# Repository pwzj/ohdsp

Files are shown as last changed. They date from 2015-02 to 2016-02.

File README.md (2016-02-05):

# README #

Open Hardware DSP Platform - www.ohdsp.org

Copyright Paul Janicki 2015

Licensed under the TAPR Open Hardware License (www.tapr.org/OHL)

This documentation is distributed WITHOUT ANY EXPRESS OR IMPLIED WARRANTY, INCLUDING OF MERCHANTABILITY, SATISFACTORY QUALITY AND FITNESS FOR A PARTICULAR PURPOSE.

### What is this repository for? ###

* Quick summary

This is an (outdated) open hardware DSP platform repository. 

Please visit www.ohdsp.org and github.com/ohdsp for the latest design files and information.

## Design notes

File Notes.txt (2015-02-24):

ADAU1452:
Pn 26 SS_M/MP0 - Self boot - needs 10k pull down to GND for i2c self boot

Solders:
Bi-Sn - low temp lead free solder
http://uk.farnell.com/edsyn/cr11/solder-paste-58-42-138-deg-10g/dp/2131462

PSU:
Use LM317/337 with teddy regs!
http://www.pinkfishmedia.net/forum/showthread.php?t=39990
http://www.pinkfishmedia.net/forum/showthread.php?t=39306

Raspberry Pi Connections:
http://www.robot-electronics.co.uk/htm/raspberry_pi_examples.htm
http://pi.gadgetoid.com/pinout
http://uk.farnell.com/harwin/m20-6102045/socket-pc-104-stackthru-40way/dp/1569230
http://uk.farnell.com/te-connectivity-amp/2-534206-0/connector-receptacle-tht-40way/dp/2310167

ADI USB/I2C:
http://www.analog.com/static/imported-files/user_guides/EVAL-ADAU1452MINIZ_User_Guide.pdf

PCB Slide Switches:
http://uk.farnell.com/c-k-components/bd01/switch-1-way-spst-tht/dp/2319976

Pi I2S Info: VERY USEFUL - INFO ON CLOCKS
https://hifiduino.wordpress.com/2014/11/13/raspberry-pi-b-digital-audio/

AKM DAC Notes:
https://hifiduino.wordpress.com/2014/12/07/akm-verita-4490-dac/

PCB trace impedance:
http://chemandy.com/calculators/coplanar-waveguide-with-ground-calculator.htm

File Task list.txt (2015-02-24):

22 Jan 2015:
Add 4.7uH 4A inductor for SMPS - footprint --done 23 Jan 15

10 Feb 2015:
Add EEPROM to library - connect to master port - Done 12 Feb 15
Add Oscillator - Done 16 Feb 2015
Add thermal diode? - Note would need external temp sense IC eg ADM1032 (16 Feb 2015)
Add ADM811 to Reset - Done 12 Feb 15
Try and sequence the supplies - use two 3v3 rails, one with a soft start on enable pin, drive the 1v2 enable from 3v3 supply - done 16 Feb 15
Add raspberry pi interface to slave control port - done 16 Feb 2015
Check elektor Arduino connection and add - Just added generic I2C/SPI lines for control, also have SPI for EEPROM - 17 Feb 2015
Check eval board for ADI USB/I2C connection and add - Done 21 Feb 2015
Add raspberry pi I2S lines to one of the I2S ports - use resistors to switch to external connectors - Done 12 Feb 15

12 Feb 2015:
Add Onboard SPDIF in and DAC out? - Done 16 Feb 2015

16 Feb 2015:
Add clock fan out buffer - Done 16 Deb 2015
Do something celever with ADM811 reset power up - eg switch the power supply with pnp/npn (level translator) from DVDD so reset is low until DVDD us valid
	-- Replaced with ADM13307 and delayed supplies it correct order
Add header to allow in circuit EEPROM programming - Done 17 Feb 2015

17 Feb 2015:
Add Power Connector - screw terminals? - Done 17 Feb 2015
Delay one 3v3 supply - connect devices in right order (I2C, EEProm etc first, then DSP...) - Done 17 Feb 2015
Add protection diodes on AUXADC inputs - Done 17 Feb 2015
Add voltage clamp/polyfuse to power connectors

19 Feb 2015:
Rationalise the design!
Add a better hand solder LFCSP package - pull pad inside edges to the edge of the pad on the package

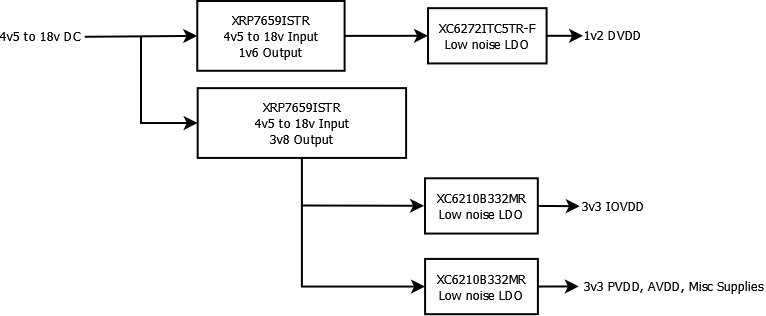
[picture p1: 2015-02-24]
Documentation/Diagrams/1. PSU/Overview V2.png

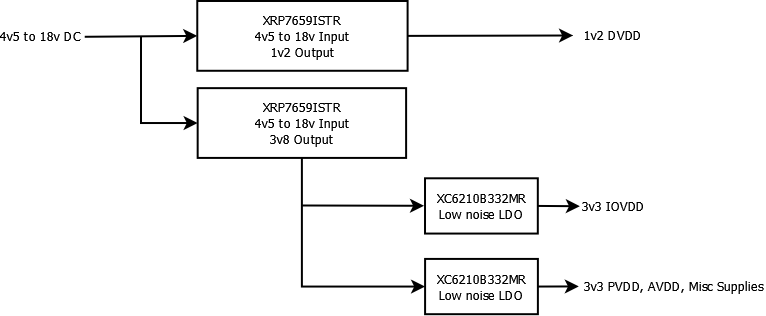
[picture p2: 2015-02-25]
Documentation/Diagrams/1. PSU/Overview V3.png

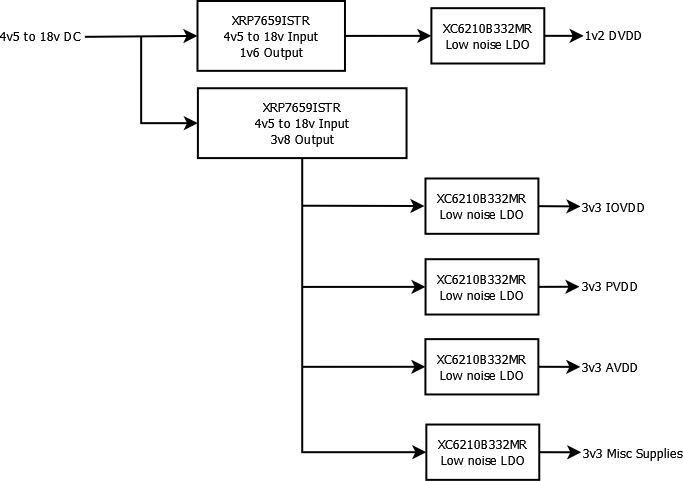
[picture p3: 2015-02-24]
Documentation/Diagrams/1. PSU/Overview.png

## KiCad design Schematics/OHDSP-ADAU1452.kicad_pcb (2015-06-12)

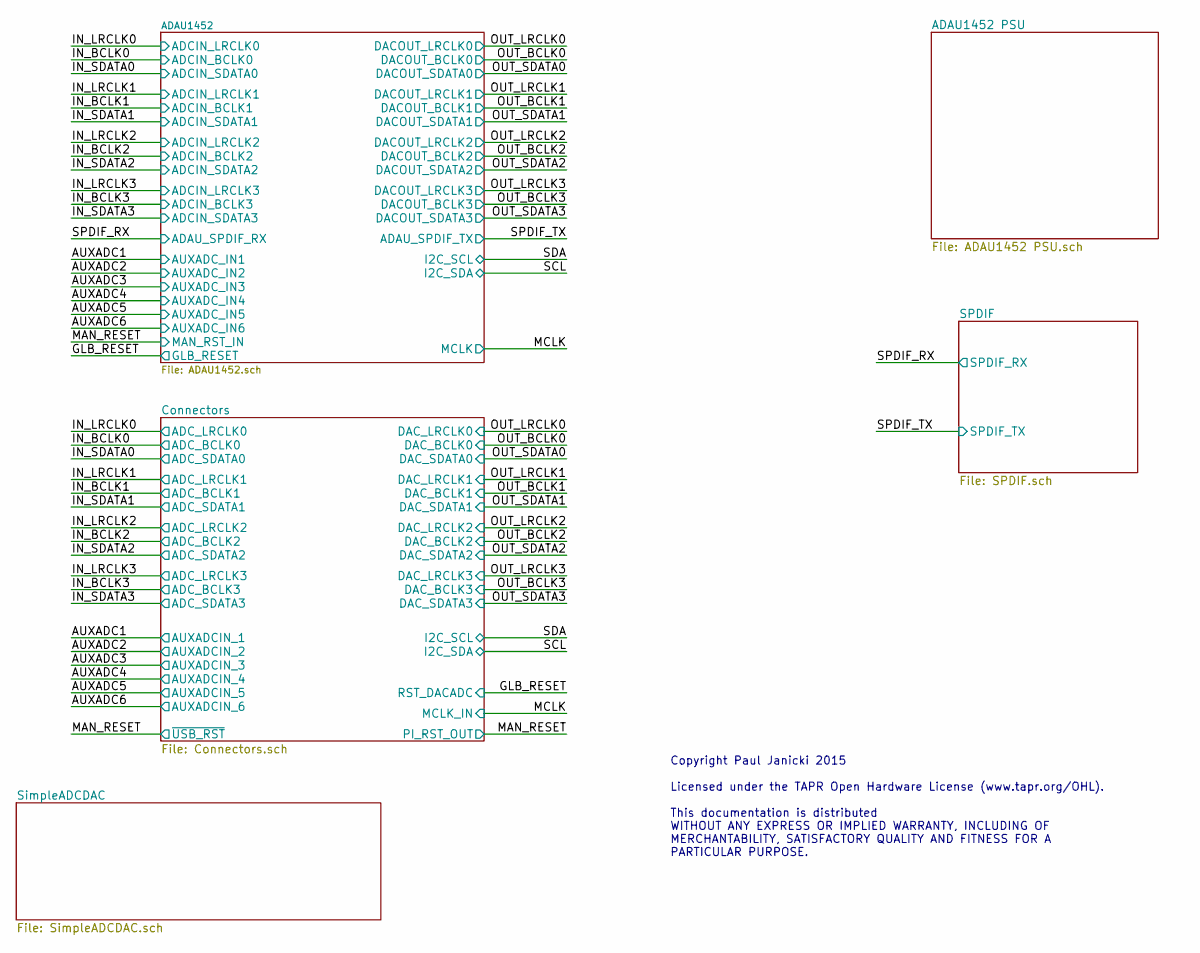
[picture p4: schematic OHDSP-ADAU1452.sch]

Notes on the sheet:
Copyright Paul Janicki 2015 Licensed under the TAPR Open Hardware License (www.tapr.org/OHL). This documentation is distributed WITHOUT ANY EXPRESS OR IMPLIED WARRANTY, INCLUDING OF MERCHANTABILITY, SATISFACTORY QUALITY AND FITNESS FOR A PARTICULAR PURPOSE.

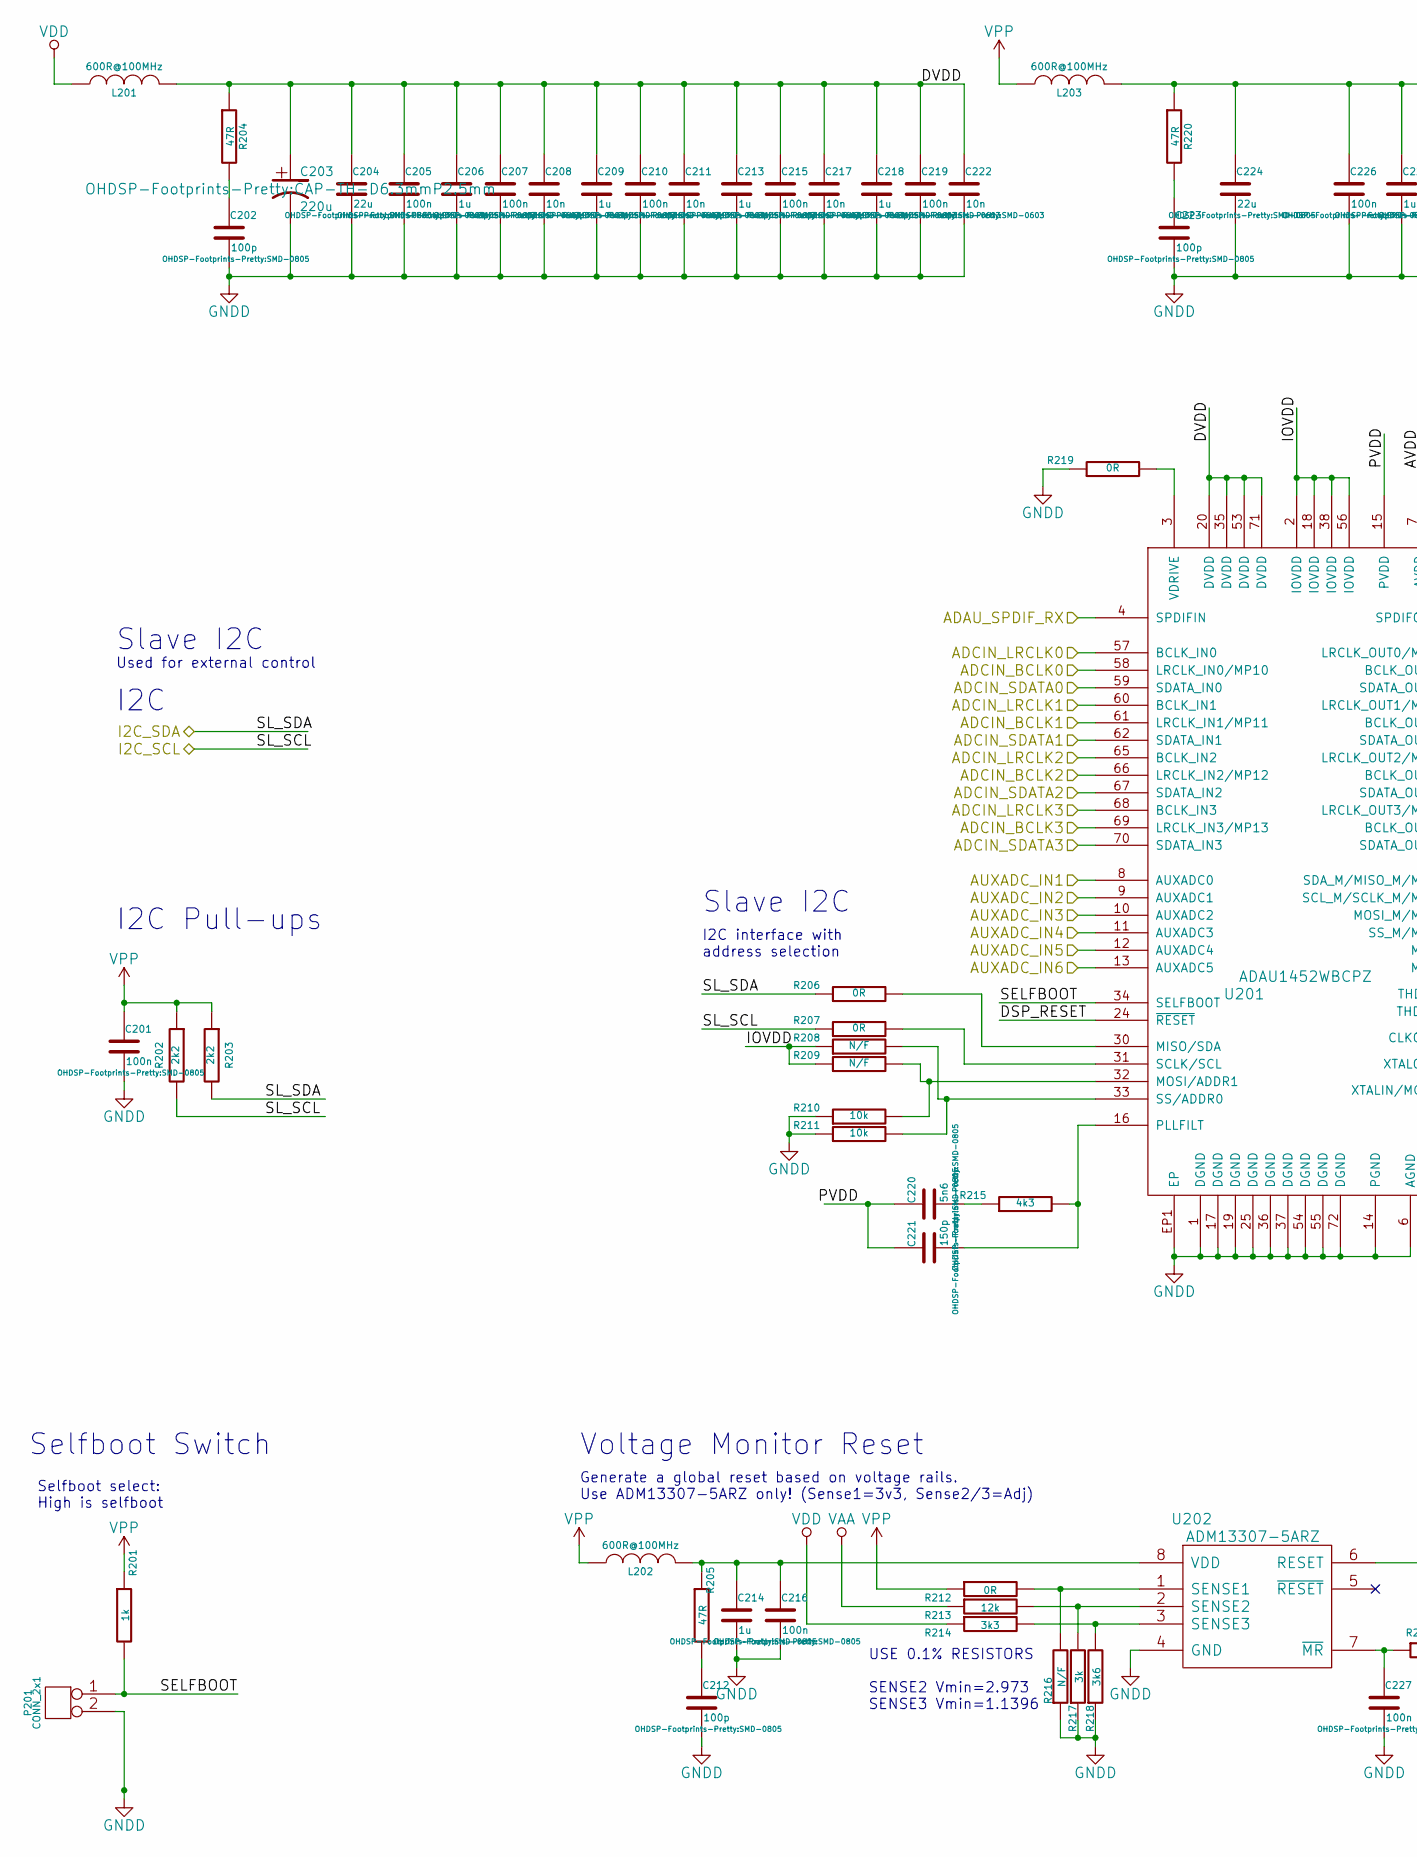
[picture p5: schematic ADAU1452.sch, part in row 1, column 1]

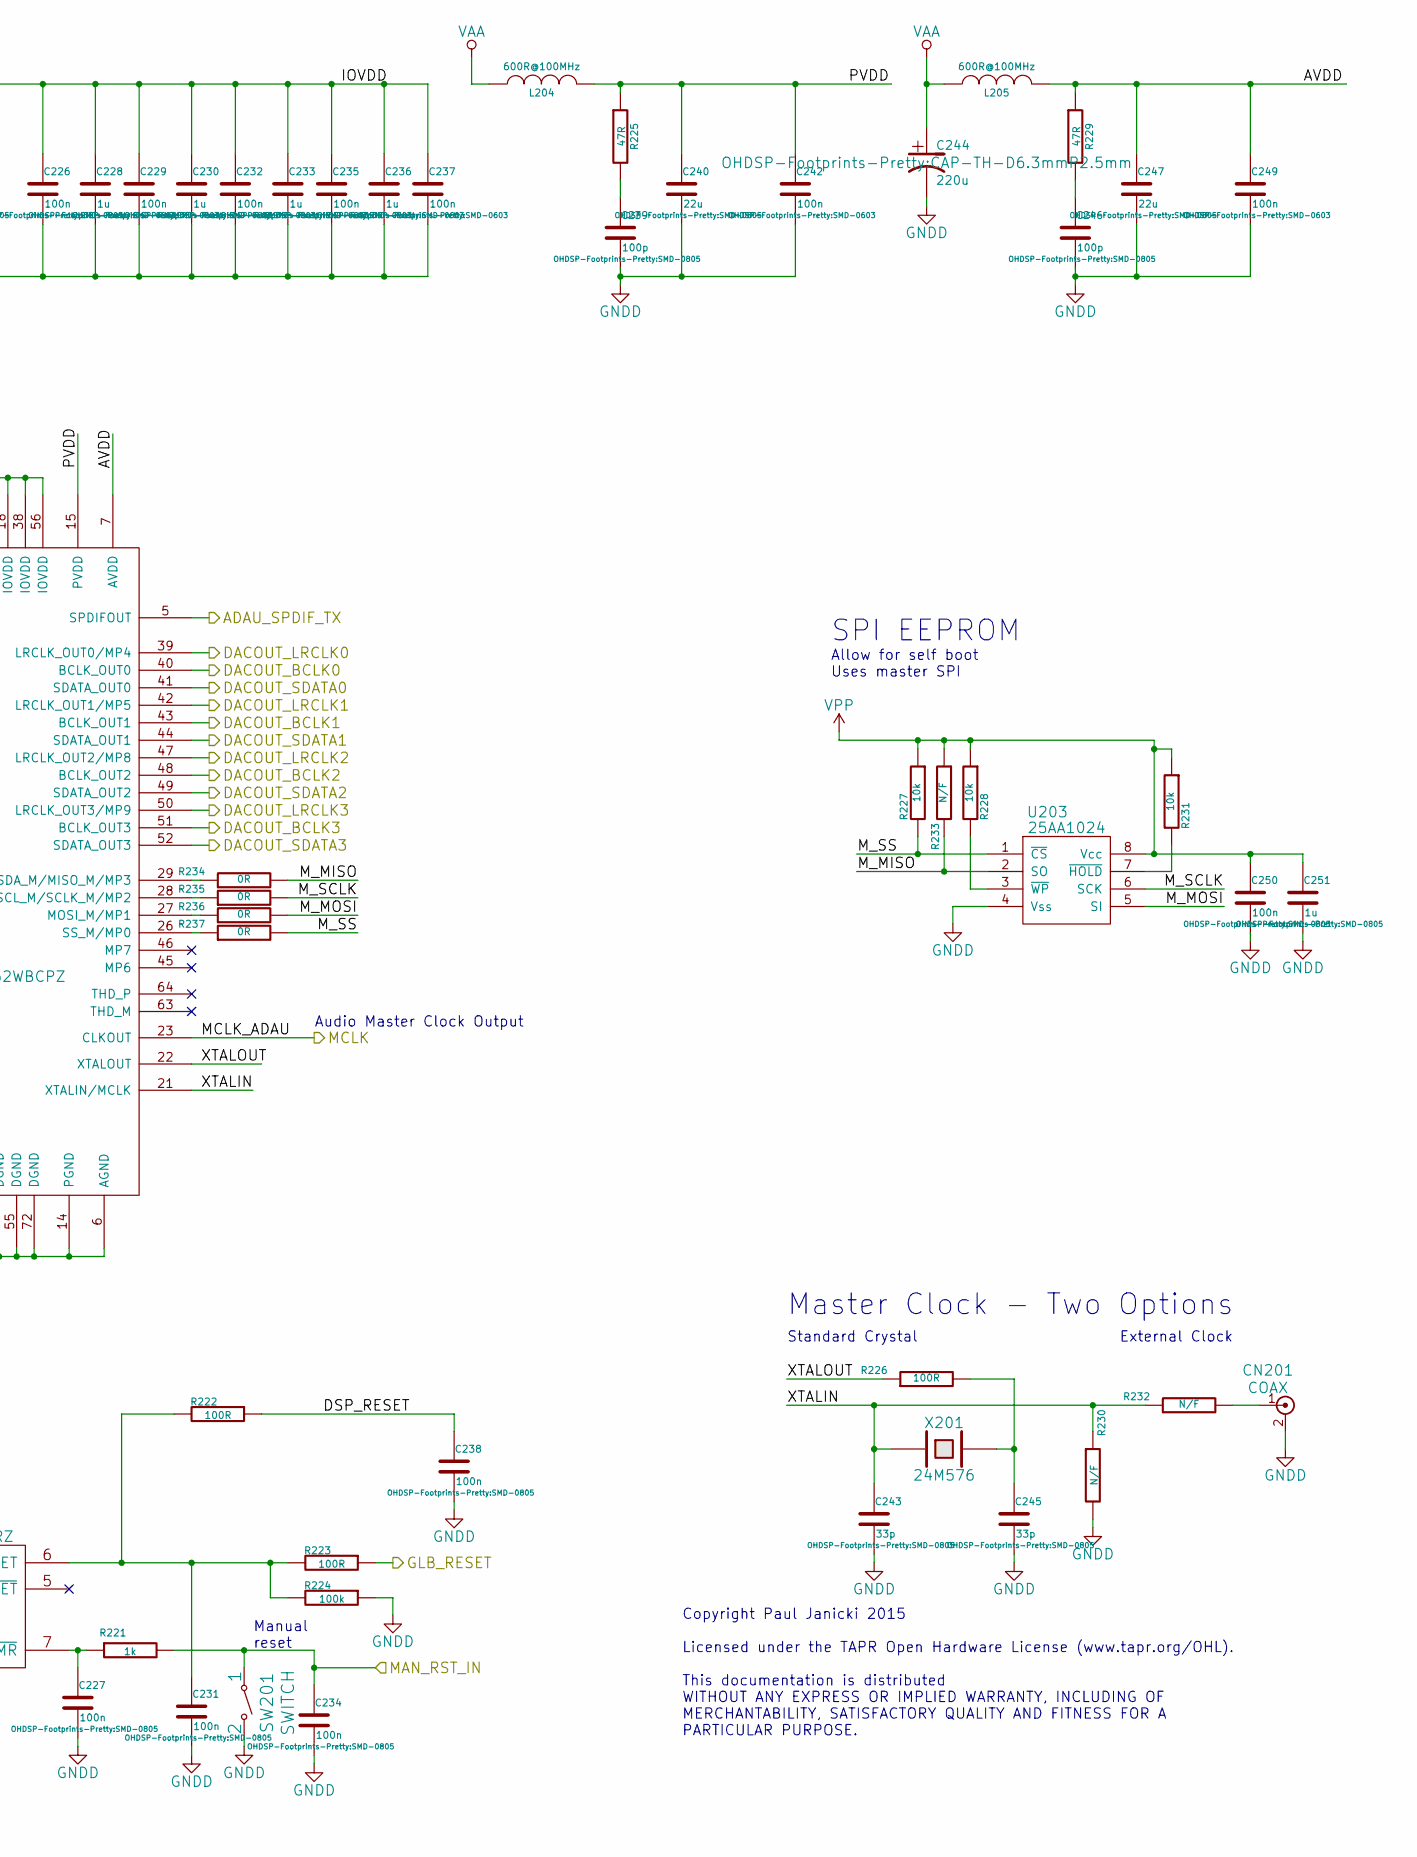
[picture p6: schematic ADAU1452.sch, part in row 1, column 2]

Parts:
C201, C205, C216, C226, C227, C231, C234, C238, C250: 100n; SMD-0805
C202, C212, C223, C239, C246: 100p; SMD-0805
C203, C244: 220u; CAP-TH-D6.3mmP2.5mm
C204, C224, C240, C247: 22u; SMD-0805
C206, C209, C213, C218, C228, C230, C233, C236: 1u; SMD-0603
C207, C210, C215, C219, C229, C232, C235, C237, C242, C249: 100n; SMD-0603
C208, C211, C217, C222: 10n; SMD-0603
C214, C251: 1u; SMD-0805
C220: 5n6; SMD-0805
C221: 150p; SMD-0805
C243, C245: 33p; SMD-0805
CN201: COAX; CONN-RF-UFL
L201, L202, L203, L204, L205: 600R@100MHz; SMD-0805
P201: CONN_2x1; CONN_SIL_2
R201, R221: 1k; SMD-0805
R202, R203: 2k2; SMD-0805
R204, R205, R220, R225, R229: 47R; SMD-0805
R206, R207, R212, R219, R234, R235, R236, R237: 0R; SMD-0805
R208, R209, R216, R230, R232, R233: N/F; SMD-0805
R210, R211, R227, R228, R231: 10k; SMD-0805
R213: 12k; SMD-0805
R214: 3k3; SMD-0805
R215: 4k3; SMD-0805
R217: 3k; SMD-0805
R218: 3k6; SMD-0805
R222, R223, R226: 100R; SMD-0805
R224: 100k; SMD-0805
SW201: SWITCH; SW_TACT_SMD
U201: ADAU1452WBCPZ; IC-LFCSP72-HANDFIT
U202: ADM13307-5ARZ; IC_SOIC_8
U203: 25AA1024; IC_DIP_8
X201: 24M576; XTAL_HC49_TH

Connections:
/ADAU1452/ADAU_SPDIF_RX: U201.4 (SPDIFIN); also elsewhere on the board
/ADAU1452/ADAU_SPDIF_TX: U201.5 (SPDIFOUT); also elsewhere on the board
/ADAU1452/ADCIN_BCLK0: U201.58 (LRCLK_IN0/MP10); also elsewhere on the board
/ADAU1452/ADCIN_BCLK1: U201.61 (LRCLK_IN1/MP11); also elsewhere on the board
/ADAU1452/ADCIN_BCLK2: U201.66 (LRCLK_IN2/MP12); also elsewhere on the board
/ADAU1452/ADCIN_BCLK3: U201.69 (LRCLK_IN3/MP13); also elsewhere on the board
/ADAU1452/ADCIN_LRCLK0: U201.57 (BCLK_IN0); also elsewhere on the board
/ADAU1452/ADCIN_LRCLK1: U201.60 (BCLK_IN1); also elsewhere on the board
/ADAU1452/ADCIN_LRCLK2: U201.65 (BCLK_IN2); also elsewhere on the board
/ADAU1452/ADCIN_LRCLK3: U201.68 (BCLK_IN3); also elsewhere on the board
/ADAU1452/ADCIN_SDATA0: U201.59 (SDATA_IN0); also elsewhere on the board
/ADAU1452/ADCIN_SDATA1: U201.62 (SDATA_IN1); also elsewhere on the board
/ADAU1452/ADCIN_SDATA2: U201.67 (SDATA_IN2); also elsewhere on the board
/ADAU1452/ADCIN_SDATA3: U201.70 (SDATA_IN3); also elsewhere on the board
/ADAU1452/AVDD: C247.1, C249.1, L205.2, R229.1, U201.7 (AVDD)
/ADAU1452/DACOUT_BCLK0: U201.40 (BCLK_OUT0); also elsewhere on the board
/ADAU1452/DACOUT_BCLK1: U201.43 (BCLK_OUT1); also elsewhere on the board
/ADAU1452/DACOUT_BCLK2: U201.48 (BCLK_OUT2); also elsewhere on the board
/ADAU1452/DACOUT_BCLK3: U201.51 (BCLK_OUT3); also elsewhere on the board
/ADAU1452/DACOUT_LRCLK0: U201.39 (LRCLK_OUT0/MP4); also elsewhere on the board
/ADAU1452/DACOUT_LRCLK1: U201.42 (LRCLK_OUT1/MP5); also elsewhere on the board
/ADAU1452/DACOUT_LRCLK2: U201.47 (LRCLK_OUT2/MP8); also elsewhere on the board
/ADAU1452/DACOUT_LRCLK3: U201.50 (LRCLK_OUT3/MP9); also elsewhere on the board
/ADAU1452/DACOUT_SDATA0: U201.41 (SDATA_OUT0); also elsewhere on the board
/ADAU1452/DACOUT_SDATA1: U201.44 (SDATA_OUT1); also elsewhere on the board
/ADAU1452/DACOUT_SDATA2: U201.49 (SDATA_OUT2); also elsewhere on the board
/ADAU1452/DACOUT_SDATA3: U201.52 (SDATA_OUT3); also elsewhere on the board
/ADAU1452/DSP_RESET: C238.1, R222.1, U201.24 (~RESET)
/ADAU1452/DVDD: C203.1, C204.1, C205.1, C206.1, C207.1, C208.1, C209.1, C210.1, C211.1, C213.1, C215.1, C217.1, C218.1, C219.1, C222.1, L201.2, R204.1, U201.20 (DVDD), U201.35 (DVDD), U201.53 (DVDD), U201.71 (DVDD)
/ADAU1452/GLB_RESET: R223.1; also elsewhere on the board
/ADAU1452/I2C_SCL: R202.2, R207.1; also elsewhere on the board
/ADAU1452/I2C_SDA: R203.2, R206.1; also elsewhere on the board
/ADAU1452/IOVDD: C224.1, C226.1, C228.1, C229.1, C230.1, C232.1, C233.1, C235.1, C236.1, C237.1, L203.2, R208.1, R209.1, R220.1, U201.2 (IOVDD), U201.18 (IOVDD), U201.38 (IOVDD), U201.56 (IOVDD)
/ADAU1452/MAN_RST_IN: C234.1, R221.2, SW201.1; also elsewhere on the board
/ADAU1452/MCLK: U201.23 (CLKOUT); also elsewhere on the board
/ADAU1452/M_MISO: R233.2, R234.2, U203.2 (SO)
/ADAU1452/M_MOSI: R236.2, U203.5 (SI)
/ADAU1452/M_SCLK: R235.2, U203.6 (SCK)
/ADAU1452/M_SS: R227.2, R237.2, U203.1 (~CS)
/ADAU1452/PVDD: C220.1, C221.1, C240.1, C242.1, L204.2, R225.1, U201.15 (PVDD)
/ADAU1452/SELFBOOT: P201.1, R201.2, U201.34 (SELFBOOT)
/ADAU1452/XTALIN: C243.1, R230.1, R232.1, U201.21 (XTALIN/MCLK), X201.1
/ADAU1452/XTALOUT: R226.1, U201.22 (XTALOUT)
/Connectors/AUXADCIN_1: U201.8 (AUXADC0); also elsewhere on the board
/Connectors/AUXADCIN_2: U201.9 (AUXADC1); also elsewhere on the board
/Connectors/AUXADCIN_3: U201.10 (AUXADC2); also elsewhere on the board
/Connectors/AUXADCIN_4: U201.11 (AUXADC3); also elsewhere on the board
/Connectors/AUXADCIN_5: U201.12 (AUXADC4); also elsewhere on the board
/Connectors/AUXADCIN_6: U201.13 (AUXADC5); also elsewhere on the board
GNDD: C201.2, C202.2, C203.2, C204.2, C205.2, C206.2, C207.2, C208.2, C209.2, C210.2, C211.2, C212.2, C213.2, C214.2, C215.2, C216.2, C217.2, C218.2, C219.2, C222.2, C223.2, C224.2, C226.2, C227.2, C228.2, C229.2, C230.2, C231.2, C232.2, C233.2, C234.2, C235.2, C236.2, C237.2, C238.2, C239.2, C240.2, C242.2, C243.2, C244.2, C245.2, C246.2, C247.2, C249.2, C250.2, C251.2, CN201.2, P201.2, R210.1, R211.1, R216.1, R217.1, R218.1, R219.1, R224.1, R230.2, SW201.2, U201.1 (DGND), U201.6 (AGND), U201.14 (PGND), U201.17 (DGND), U201.19 (DGND), U201.25 (DGND), U201.36 (DGND), U201.37 (DGND), U201.54 (DGND), U201.55 (DGND), U201.72 (DGND), U201.EP1 (EP), U202.4 (GND), U203.4 (Vss); also elsewhere on the board
unnamed: C202.1, R204.2
unnamed: C212.1, R205.2
unnamed: C214.1, C216.1, L202.2, R205.1, U202.8 (VDD)
unnamed: C220.2, R215.1
unnamed: C221.2, R215.2, U201.16 (PLLFILT)
unnamed: C223.1, R220.2
unnamed: C227.1, R221.1, U202.7 (~MR)
unnamed: C231.1, R222.2, R223.2, R224.2, U202.6 (RESET)
unnamed: C239.1, R225.2
unnamed: C245.1, R226.2, X201.2
unnamed: C246.1, R229.2
unnamed: CN201.1, R232.2
unnamed: R206.2, U201.30 (MISO/SDA)
unnamed: R207.2, U201.31 (SCLK/SCL)
unnamed: R208.2, R211.2, U201.33 (SS/ADDR0)
unnamed: R209.2, R210.2, U201.32 (MOSI/ADDR1)
unnamed: R212.2, R216.2, U202.1 (SENSE1)
unnamed: R213.2, R217.2, U202.2 (SENSE2)
unnamed: R214.2, R218.2, U202.3 (SENSE3)
unnamed: R219.2, U201.3 (VDRIVE)
unnamed: R228.2, U203.3 (~WP)
unnamed: R231.2, U203.7 (~HOLD)
unnamed: R234.1, U201.29 (SDA_M/MISO_M/MP3)
unnamed: R235.1, U201.28 (SCL_M/SCLK_M/MP2)
unnamed: R236.1, U201.27 (MOSI_M/MP1)
unnamed: R237.1, U201.26 (SS_M/MP0)
VAA: C201.1, C244.1, C250.1, C251.1, L202.1, L203.1, L204.1, L205.1, R201.1, R202.1, R203.1, R212.1, R213.1, R227.1, R228.1, R231.1, R233.1, U203.8 (Vcc); also elsewhere on the board
VDD: L201.1, R214.1; also elsewhere on the board

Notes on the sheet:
Selfboot Switch
Selfboot select: High is selfboot
Generate a global reset based on voltage rails. Use ADM13307-5ARZ only! (Sense1=3v3, Sense2/3=Adj)
Voltage Monitor Reset
SPI EEPROM
I2C Pull-ups
I2C
Master Clock - Two Options
Standard Crystal
Allow for self boot Uses master SPI
Slave I2C
Used for external control
I2C interface with address selection
Audio Master Clock Output
Manual reset
USE 0.1% RESISTORS SENSE2 Vmin=2.973 SENSE3 Vmin=1.1396
Copyright Paul Janicki 2015 Licensed under the TAPR Open Hardware License (www.tapr.org/OHL). This documentation is distributed WITHOUT ANY EXPRESS OR IMPLIED WARRANTY, INCLUDING OF MERCHANTABILITY, SATISFACTORY QUALITY AND FITNESS FOR A PARTICULAR PURPOSE.
External Clock

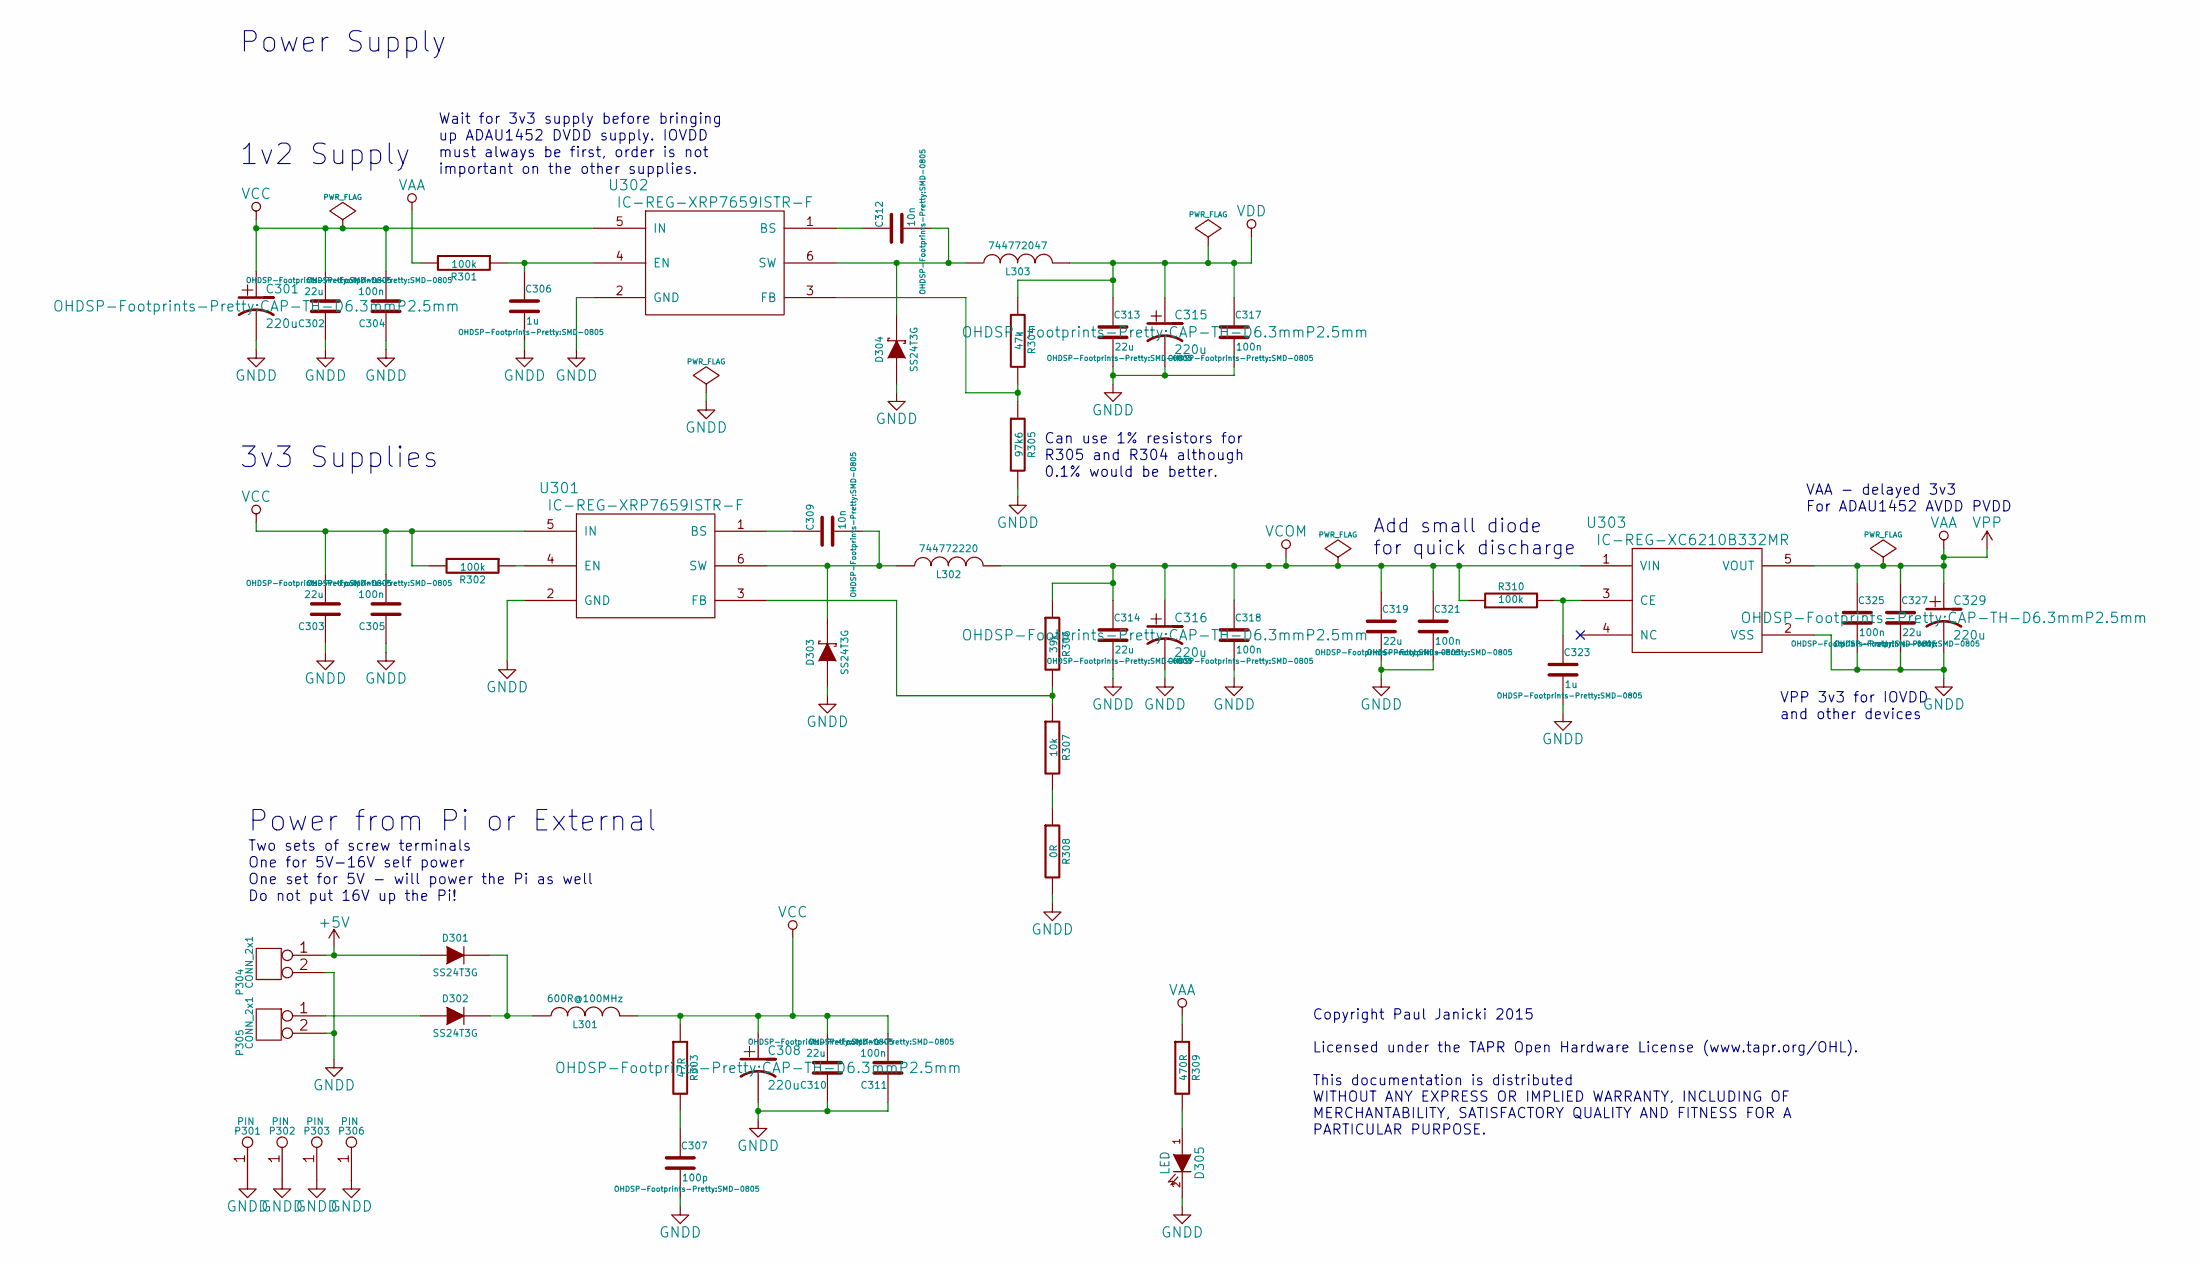
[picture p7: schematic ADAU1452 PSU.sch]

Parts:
C301, C308, C315, C316, C329: 220u; CAP-TH-D6.3mmP2.5mm
C302, C303, C310, C313, C314, C319, C327: 22u; SMD-0805
C304, C305, C311, C317, C318, C321, C325: 100n; SMD-0805
C306, C323: 1u; SMD-0805
C307: 100p; SMD-0805
C309, C312: 10n; SMD-0805
D301, D302, D303, D304: SS24T3G; DIODE-SMB
D305: LED; SMD-1206
L301: 600R@100MHz; SMD-0805
L302: 744772220; PASSIVE-TH-IND-WURTH-5mm
L303: 744772047; PASSIVE-TH-IND-WURTH-5mm
P301, P302, P303, P306: PIN; MNT_HOLE_2.5mm
P304, P305: CONN_2x1; CONN-SCREW-2WAY-5mm-5.08mm
R301, R302, R310: 100k; SMD-0805
R303: 47R; SMD-0805
R304: 47k; SMD-0805
R305: 97k6; SMD-0805
R306: 39k; SMD-0805
R307: 10k; SMD-0805
R308: 0R; SMD-0805
R309: 470R; SMD-0805
U301, U302: IC-REG-XRP7659ISTR-F; IC-SOT23-6
U303: IC-REG-XC6210B332MR; IC-SOT25

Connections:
+5V: D301.1 (A), P304.1; also elsewhere on the board
GNDD: C301.2, C302.1, C303.1, C304.1, C305.1, C306.2, C307.2, C308.2, C310.1, C311.1, C313.2, C314.2, C315.2, C316.2, C317.2, C318.2, C319.2, C321.2, C323.2, C325.2, C327.2, C329.2, D303.1 (A), D304.1 (A), D305.2 (K), P301.1, P302.1, P303.1, P304.2, P305.2, P306.1, R305.2, R308.2, U301.2 (GND), U302.2 (GND), U303.2 (VSS); also elsewhere on the board
unnamed: C306.1, R301.1, U302.4 (EN)
unnamed: C307.1, R303.2
unnamed: C309.1, U301.1 (BS)
unnamed: C309.2, D303.2 (K), L302.1, U301.6 (SW)
unnamed: C312.1, U302.1 (BS)
unnamed: C312.2, D304.2 (K), L303.1, U302.6 (SW)
unnamed: C323.1, R310.2, U303.3 (CE)
unnamed: D301.2 (K), D302.2 (K), L301.1
unnamed: D302.1 (A), P305.1
unnamed: D305.1 (A), R309.2
unnamed: R302.1, U301.4 (EN)
unnamed: R304.2, R305.1, U302.3 (FB)
unnamed: R306.2, R307.1, U301.3 (FB)
unnamed: R307.2, R308.1
VAA: C325.1, C327.1, C329.1, R301.2, R309.1, U303.5 (VOUT); also elsewhere on the board
VCC: C301.1, C302.2, C303.2, C304.2, C305.2, C308.1, C310.2, C311.2, L301.2, R302.2, R303.1, U301.5 (IN), U302.5 (IN)
VCOM: C314.1, C316.1, C318.1, C319.1, C321.1, L302.2, R306.1, R310.1, U303.1 (VIN)
VDD: C313.1, C315.1, C317.1, L303.2, R304.1; also elsewhere on the board

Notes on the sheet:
Wait for 3v3 supply before bringing up ADAU1452 DVDD supply. IOVDD must always be first, order is not important on the other supplies.
Power Supply
1v2 Supply
3v3 Supplies
VAA - delayed 3v3 For ADAU1452 AVDD PVDD
VPP 3v3 for IOVDD and other devices
Power from Pi or External
Two sets of screw terminals One for 5V-16V self power One set for 5V - will power the Pi as well Do not put 16V up the Pi!
Copyright Paul Janicki 2015 Licensed under the TAPR Open Hardware License (www.tapr.org/OHL). This documentation is distributed WITHOUT ANY EXPRESS OR IMPLIED WARRANTY, INCLUDING OF MERCHANTABILITY, SATISFACTORY QUALITY AND FITNESS FOR A PARTICULAR PURPOSE.
Add small diode for quick discharge
Can use 1% resistors for R305 and R304 although 0.1% would be better.

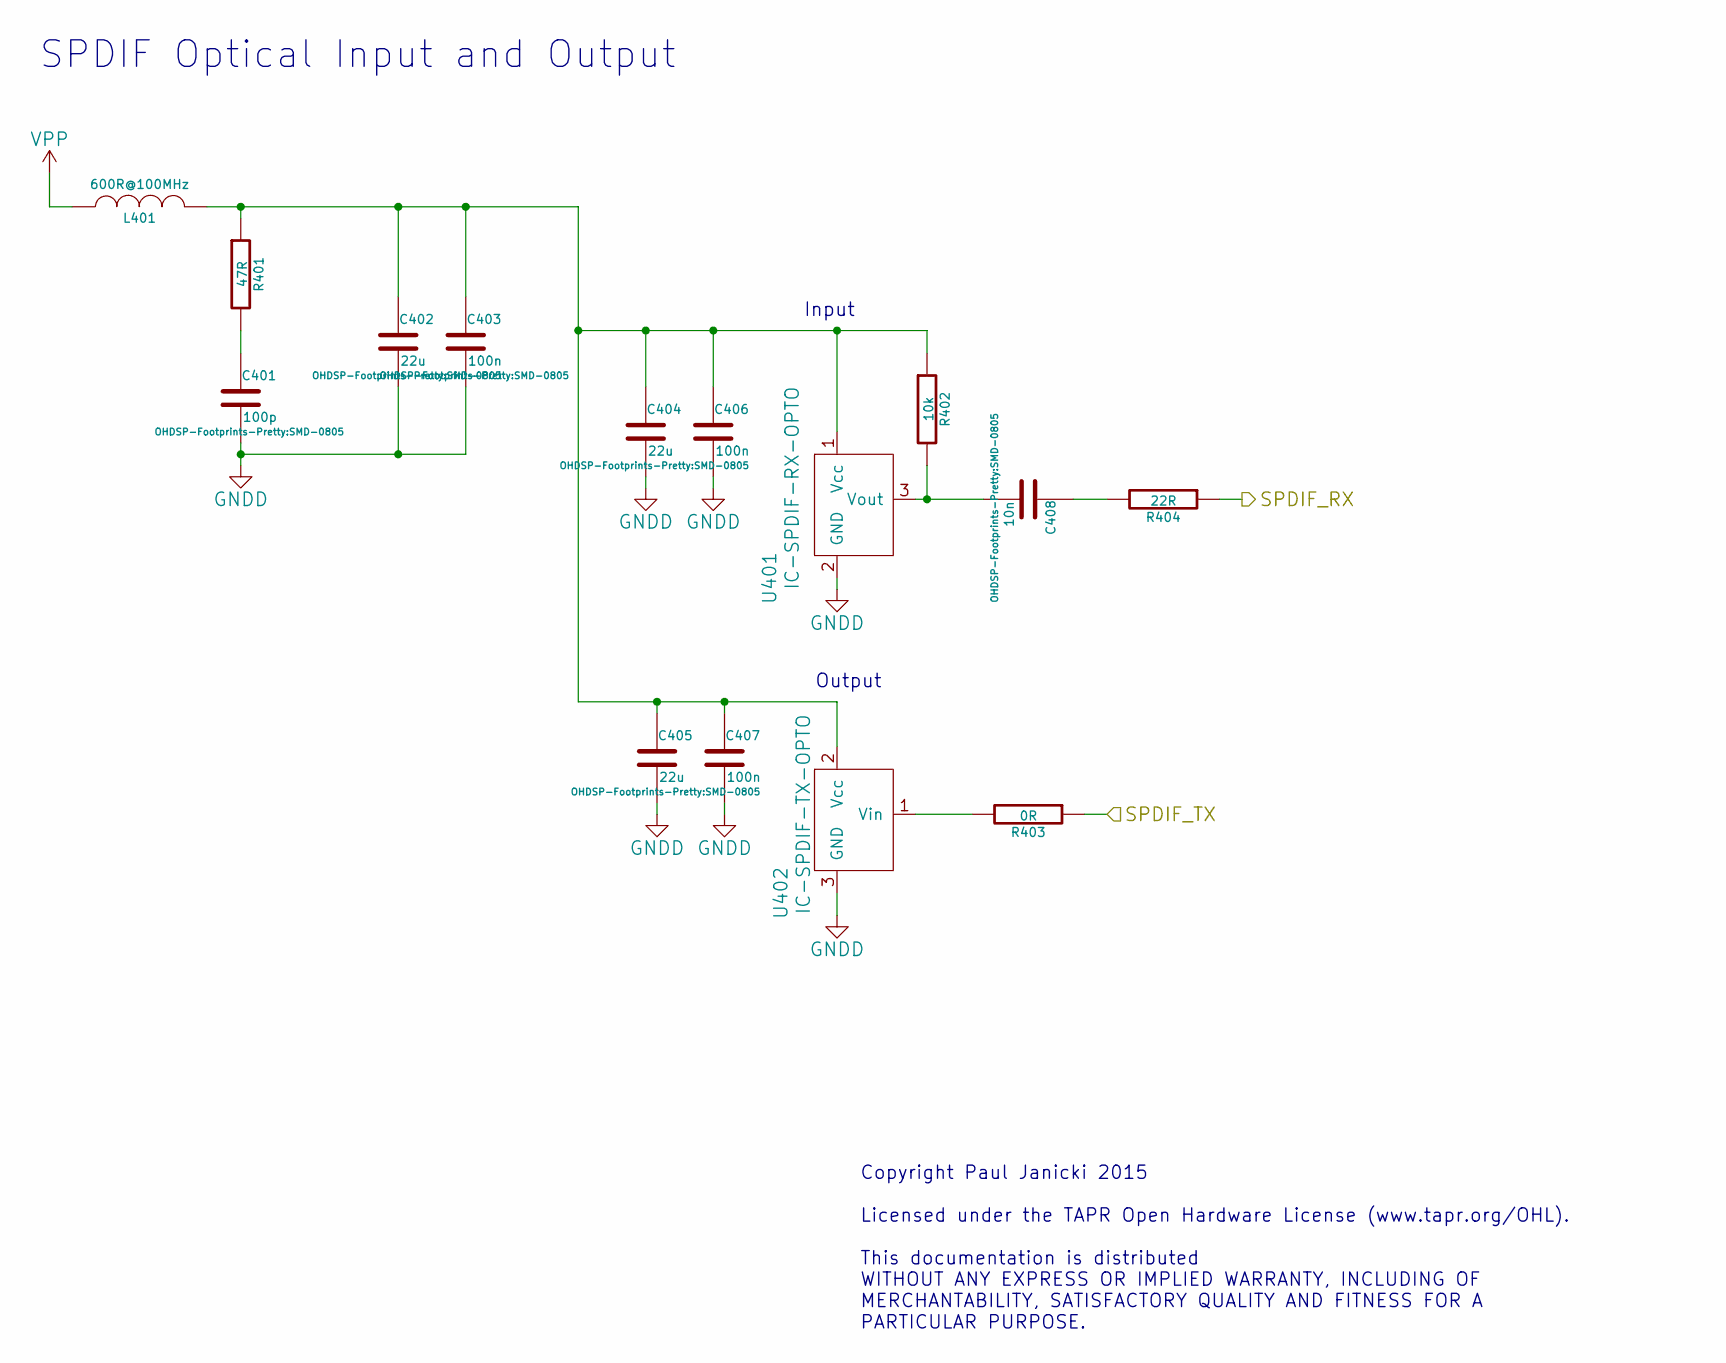
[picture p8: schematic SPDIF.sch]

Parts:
C401: 100p; SMD-0805
C402, C404, C405: 22u; SMD-0805
C403, C406, C407: 100n; SMD-0805
C408: 10n; SMD-0805
L401: 600R@100MHz; SMD-0805
R401: 47R; SMD-0805
R402: 10k; SMD-0805
R403: 0R; SMD-0805
R404: 22R; SMD-0805
U401: IC-SPDIF-RX-OPTO; IC_SPDIF_OPTO
U402: IC-SPDIF-TX-OPTO; IC_SPDIF_OPTO

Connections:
/ADAU1452/ADAU_SPDIF_RX: R404.1; also elsewhere on the board
/ADAU1452/ADAU_SPDIF_TX: R403.1; also elsewhere on the board
GNDD: C401.2, C402.2, C403.2, C404.2, C405.2, C406.2, C407.2, U401.2 (GND), U402.3 (GND); also elsewhere on the board
unnamed: C401.1, R401.2
unnamed: C402.1, C403.1, C404.1, C405.1, C406.1, C407.1, L401.2, R401.1, R402.1, U401.1 (Vcc), U402.2 (Vcc)
unnamed: C408.1, R404.2
unnamed: C408.2, R402.2, U401.3 (Vout)
unnamed: R403.2, U402.1 (Vin)
VAA: L401.1; also elsewhere on the board

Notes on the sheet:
SPDIF Optical Input and Output
Input
Output
Copyright Paul Janicki 2015 Licensed under the TAPR Open Hardware License (www.tapr.org/OHL). This documentation is distributed WITHOUT ANY EXPRESS OR IMPLIED WARRANTY, INCLUDING OF MERCHANTABILITY, SATISFACTORY QUALITY AND FITNESS FOR A PARTICULAR PURPOSE.

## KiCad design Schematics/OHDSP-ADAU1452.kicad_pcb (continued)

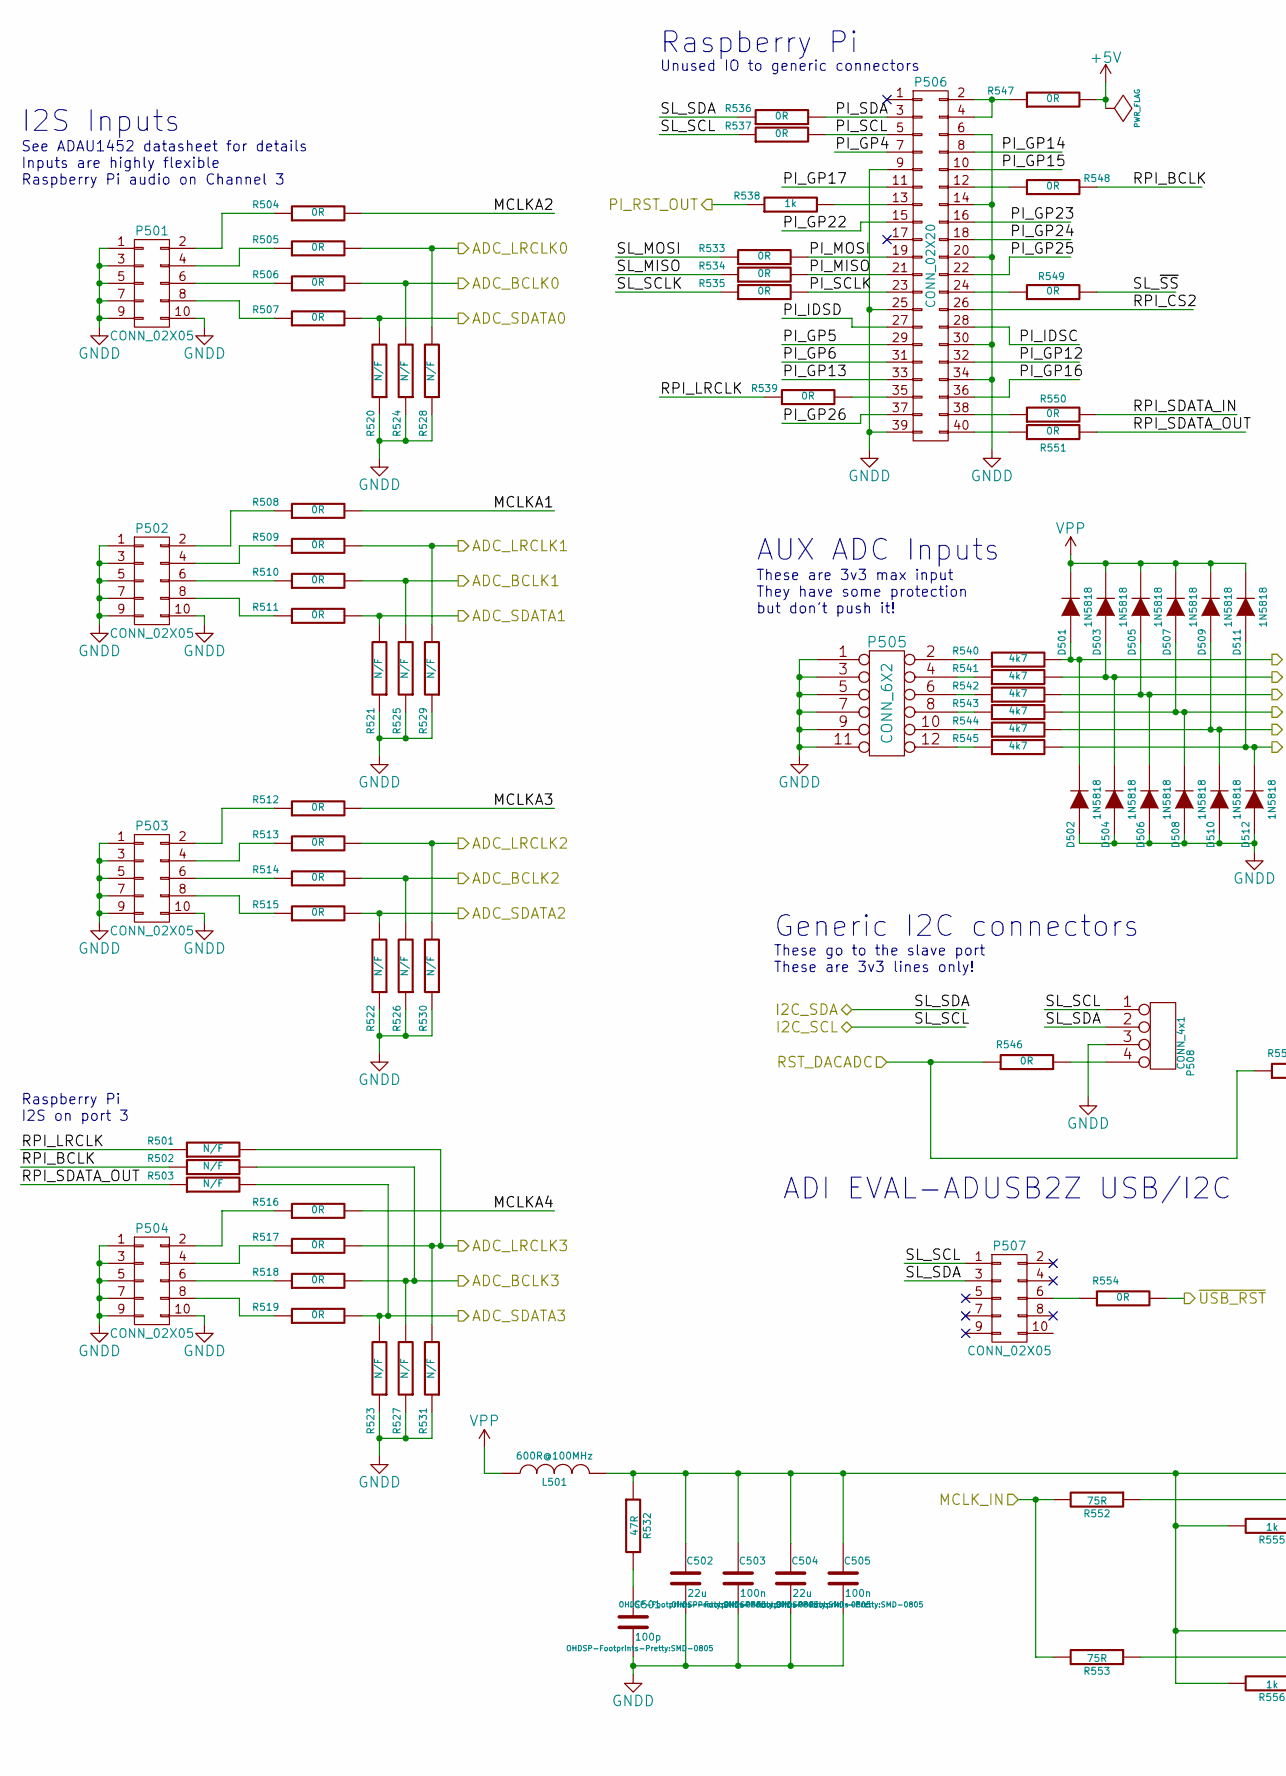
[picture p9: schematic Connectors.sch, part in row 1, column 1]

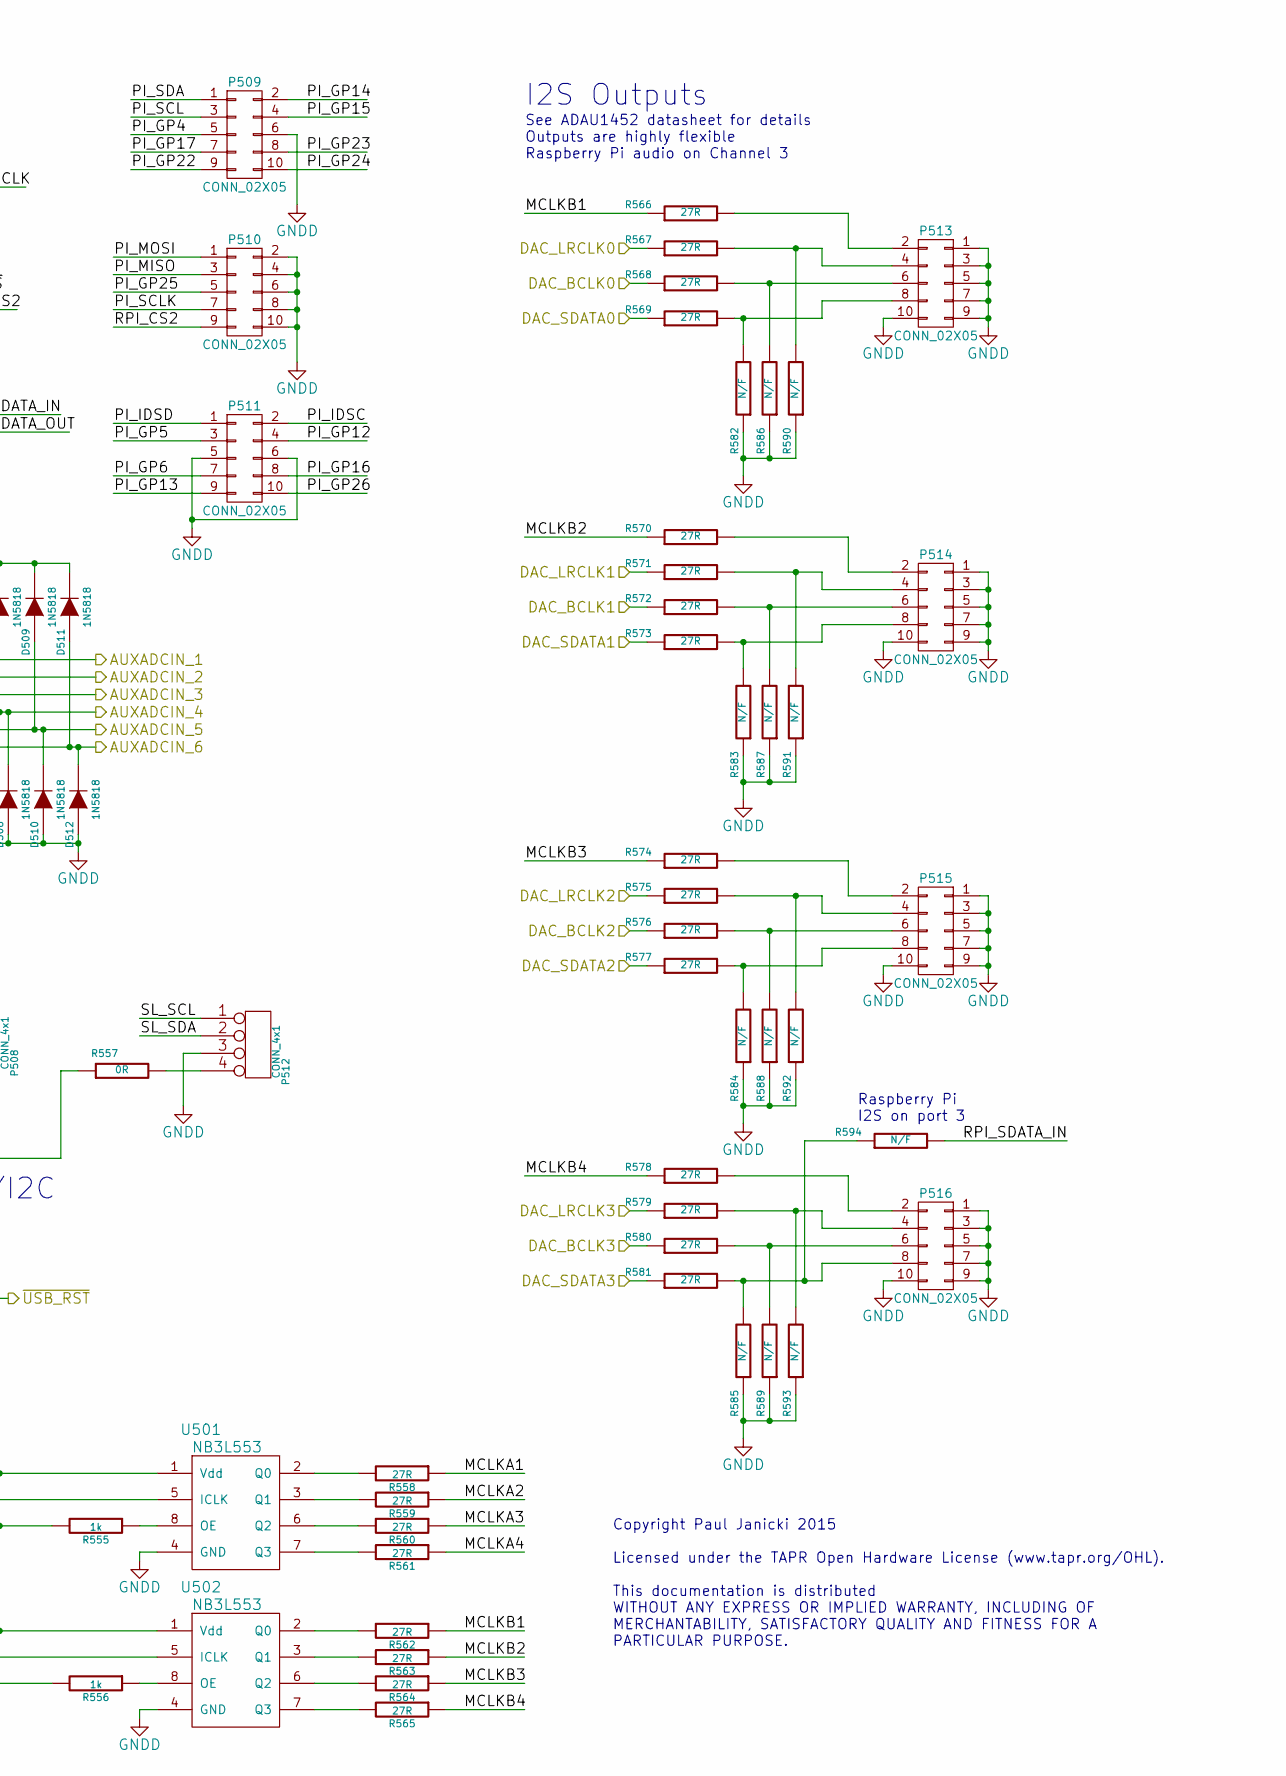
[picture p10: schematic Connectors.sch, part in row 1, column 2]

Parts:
C501: 100p; SMD-0805
C502, C504: 22u; SMD-0805
C503, C505: 100n; SMD-0805
D501, D502, D503, D504, D505, D506, D507, D508, D509, D510, D511, D512: 1N5818; DIODE-DO-41
L501: 600R@100MHz; SMD-0805
P501, P502, P503, P504, P507, P513, P514, P515, P516: CONN_02X05; CONN_DIL_2X5_BOX
P505: CONN_6X2; CONN_DIL_2X6
P506: CONN_02X20; CONN_DIL_2X20
P508, P512: CONN_4x1; CONN_SIL_4
P509, P510, P511: CONN_02X05; CONN_DIL_2X5
R501, R502, R503, R520, R521, R522, R523, R524, R525, R526, R527, R528, R529, R530, R531, R582, R583, R584, R585, R586, R587, R588, R589, R590, R591, R592, R593, R594: N/F; SMD-0805
R504, R505, R506, R507, R508, R509, R510, R511, R512, R513, R514, R515, R516, R517, R518, R519, R533, R534, R535, R536, R537, R539, R546, R547, R548, R549, R550, R551, R554, R557: 0R; SMD-0805
R532: 47R; SMD-0805
R538, R555, R556: 1k; SMD-0805
R540, R541, R542, R543, R544, R545: 4k7; SMD-0805
R552, R553: 75R; SMD-0805
R558, R559, R560, R561, R562, R563, R564, R565, R566, R567, R568, R569, R570, R571, R572, R573, R574, R575, R576, R577, R578, R579, R580, R581: 27R; SMD-0805
U501, U502: NB3L553; IC_SOIC_8

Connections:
+5V: R547.2; also elsewhere on the board
/ADAU1452/ADCIN_BCLK0: R506.2, R524.2; also elsewhere on the board
/ADAU1452/ADCIN_BCLK1: R510.2, R525.2; also elsewhere on the board
/ADAU1452/ADCIN_BCLK2: R514.2, R526.2; also elsewhere on the board
/ADAU1452/ADCIN_BCLK3: R502.2, R518.2, R527.2; also elsewhere on the board
/ADAU1452/ADCIN_LRCLK0: R505.2, R528.2; also elsewhere on the board
/ADAU1452/ADCIN_LRCLK1: R509.2, R529.2; also elsewhere on the board
/ADAU1452/ADCIN_LRCLK2: R513.2, R530.2; also elsewhere on the board
/ADAU1452/ADCIN_LRCLK3: R501.2, R517.2, R531.2; also elsewhere on the board
/ADAU1452/ADCIN_SDATA0: R507.2, R520.2; also elsewhere on the board
/ADAU1452/ADCIN_SDATA1: R511.2, R521.2; also elsewhere on the board
/ADAU1452/ADCIN_SDATA2: R515.2, R522.2; also elsewhere on the board
/ADAU1452/ADCIN_SDATA3: R503.2, R519.2, R523.2; also elsewhere on the board
/ADAU1452/DACOUT_BCLK0: R568.1; also elsewhere on the board
/ADAU1452/DACOUT_BCLK1: R572.1; also elsewhere on the board
/ADAU1452/DACOUT_BCLK2: R576.1; also elsewhere on the board
/ADAU1452/DACOUT_BCLK3: R580.1; also elsewhere on the board
/ADAU1452/DACOUT_LRCLK0: R567.1; also elsewhere on the board
/ADAU1452/DACOUT_LRCLK1: R571.1; also elsewhere on the board
/ADAU1452/DACOUT_LRCLK2: R575.1; also elsewhere on the board
/ADAU1452/DACOUT_LRCLK3: R579.1; also elsewhere on the board
/ADAU1452/DACOUT_SDATA0: R569.1; also elsewhere on the board
/ADAU1452/DACOUT_SDATA1: R573.1; also elsewhere on the board
/ADAU1452/DACOUT_SDATA2: R577.1; also elsewhere on the board
/ADAU1452/DACOUT_SDATA3: R581.1; also elsewhere on the board
/ADAU1452/GLB_RESET: R546.1, R557.1; also elsewhere on the board
/ADAU1452/I2C_SCL: P507.1, P508.1, P512.1, R537.1; also elsewhere on the board
/ADAU1452/I2C_SDA: P507.3, P508.2, P512.2, R536.1; also elsewhere on the board
/ADAU1452/MAN_RST_IN: R538.1, R554.2; also elsewhere on the board
/ADAU1452/MCLK: R552.2, R553.2; also elsewhere on the board
/Connectors/AUXADCIN_1: D501.1 (A), D502.2 (K), R540.2; also elsewhere on the board
/Connectors/AUXADCIN_2: D503.1 (A), D504.2 (K), R541.2; also elsewhere on the board
/Connectors/AUXADCIN_3: D505.1 (A), D506.2 (K), R542.2; also elsewhere on the board
/Connectors/AUXADCIN_4: D507.1 (A), D508.2 (K), R543.2; also elsewhere on the board
/Connectors/AUXADCIN_5: D509.1 (A), D510.2 (K), R544.2; also elsewhere on the board
/Connectors/AUXADCIN_6: D511.1 (A), D512.2 (K), R545.2; also elsewhere on the board
/Connectors/MCLKA1: R508.2, R558.1
/Connectors/MCLKA2: R504.2, R559.1
/Connectors/MCLKA3: R512.2, R560.1
/Connectors/MCLKA4: R516.2, R561.1
/Connectors/MCLKB1: R562.1, R566.1
/Connectors/MCLKB2: R563.1, R570.1
/Connectors/MCLKB3: R564.1, R574.1
/Connectors/MCLKB4: R565.1, R578.1
/Connectors/PI_GP4: P506.7, P509.5
/Connectors/PI_GP5: P506.29, P511.3
/Connectors/PI_GP6: P506.31, P511.7
/Connectors/PI_GP12: P506.32, P511.4
/Connectors/PI_GP13: P506.33, P511.9
/Connectors/PI_GP14: P506.8, P509.2
/Connectors/PI_GP15: P506.10, P509.4
/Connectors/PI_GP16: P506.36, P511.8
/Connectors/PI_GP17: P506.11, P509.7
/Connectors/PI_GP22: P506.15, P509.9
/Connectors/PI_GP23: P506.16, P509.8
/Connectors/PI_GP24: P506.18, P509.10
/Connectors/PI_GP25: P506.22, P510.5
/Connectors/PI_GP26: P506.37, P511.10
/Connectors/PI_IDSC: P506.28, P511.2
/Connectors/PI_IDSD: P506.27, P511.1
/Connectors/PI_MISO: P506.21, P510.3, R534.2
/Connectors/PI_MOSI: P506.19, P510.1, R533.2
/Connectors/PI_SCL: P506.5, P509.3, R537.2
/Connectors/PI_SCLK: P506.23, P510.7, R535.2
/Connectors/PI_SDA: P506.3, P509.1, R536.2
/Connectors/RPI_BCLK: R502.1, R548.2
/Connectors/RPI_CS2: P506.26, P510.9
/Connectors/RPI_LRCLK: R501.1, R539.1
/Connectors/RPI_SDATA_IN: R550.2, R594.2
/Connectors/RPI_SDATA_OUT: R503.1, R551.2
/Connectors/SL_MISO: R534.1
/Connectors/SL_MOSI: R533.1
/Connectors/SL_SCLK: R535.1
/Connectors/SL_~SS: R549.2
GNDD: C501.2, C502.2, C503.2, C504.2, C505.2, D502.1 (A), D504.1 (A), D506.1 (A), D508.1 (A), D510.1 (A), D512.1 (A), P501.1, P501.3, P501.5, P501.7, P501.9, P501.10, P502.1, P502.3, P502.5, P502.7, P502.9, P502.10, P503.1, P503.3, P503.5, P503.7, P503.9, P503.10, P504.1, P504.3, P504.5, P504.7, P504.9, P504.10, P505.1, P505.3, P505.5, P505.7, P505.9, P505.11, P506.6, P506.9, P506.14, P506.20, P506.25, P506.30, P506.34, P506.39, P508.3, P509.6, P510.2, P510.4, P510.6, P510.8, P510.10, P511.5, P511.6, P512.3, P513.1, P513.3, P513.5, P513.7, P513.9, P513.10, P514.1, P514.3, P514.5, P514.7, P514.9, P514.10, P515.1, P515.3, P515.5, P515.7, P515.9, P515.10, P516.1, P516.3, P516.5, P516.7, P516.9, P516.10, R520.1, R521.1, R522.1, R523.1, R524.1, R525.1, R526.1, R527.1, R528.1, R529.1, R530.1, R531.1, R582.1, R583.1, R584.1, R585.1, R586.1, R587.1, R588.1, R589.1, R590.1, R591.1, R592.1, R593.1, U501.4 (GND), U502.4 (GND); also elsewhere on the board
unnamed: C501.1, R532.2
unnamed: C502.1, C503.1, C504.1, C505.1, L501.2, R532.1, R555.2, R556.2, U501.1 (Vdd), U502.1 (Vdd)
unnamed: P501.2, R504.1
unnamed: P501.4, R505.1
unnamed: P501.6, R506.1
unnamed: P501.8, R507.1
unnamed: P502.2, R508.1
unnamed: P502.4, R509.1
unnamed: P502.6, R510.1
unnamed: P502.8, R511.1
unnamed: P503.2, R512.1
unnamed: P503.4, R513.1
unnamed: P503.6, R514.1
unnamed: P503.8, R515.1
unnamed: P504.2, R516.1
unnamed: P504.4, R517.1
unnamed: P504.6, R518.1
unnamed: P504.8, R519.1
unnamed: P505.2, R540.1
unnamed: P505.4, R541.1
unnamed: P505.6, R542.1
unnamed: P505.8, R543.1
unnamed: P505.10, R544.1
unnamed: P505.12, R545.1
unnamed: P506.2, P506.4, R547.1
unnamed: P506.12, R548.1
unnamed: P506.13, R538.2
unnamed: P506.24, R549.1
unnamed: P506.35, R539.2
unnamed: P506.38, R550.1
unnamed: P506.40, R551.1
unnamed: P507.6, R554.1
unnamed: P508.4, R546.2
unnamed: P512.4, R557.2
unnamed: P513.2, R566.2
unnamed: P513.4, R567.2, R590.2
unnamed: P513.6, R568.2, R586.2
unnamed: P513.8, R569.2, R582.2
unnamed: P514.2, R570.2
unnamed: P514.4, R571.2, R591.2
unnamed: P514.6, R572.2, R587.2
unnamed: P514.8, R573.2, R583.2
unnamed: P515.2, R574.2
unnamed: P515.4, R575.2, R592.2
unnamed: P515.6, R576.2, R588.2
unnamed: P515.8, R577.2, R584.2
unnamed: P516.2, R578.2
unnamed: P516.4, R579.2, R593.2
unnamed: P516.6, R580.2, R589.2
unnamed: P516.8, R581.2, R585.2, R594.1
unnamed: R552.1, U501.5 (ICLK)
unnamed: R553.1, U502.5 (ICLK)
unnamed: R555.1, U501.8 (OE)
unnamed: R556.1, U502.8 (OE)
unnamed: R558.2, U501.2 (Q0)
unnamed: R559.2, U501.3 (Q1)
unnamed: R560.2, U501.6 (Q2)
unnamed: R561.2, U501.7 (Q3)
unnamed: R562.2, U502.2 (Q0)
unnamed: R563.2, U502.3 (Q1)
unnamed: R564.2, U502.6 (Q2)
unnamed: R565.2, U502.7 (Q3)
VAA: D501.2 (K), D503.2 (K), D505.2 (K), D507.2 (K), D509.2 (K), D511.2 (K), L501.1; also elsewhere on the board

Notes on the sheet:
ADI EVAL-ADUSB2Z USB/I2C
Raspberry Pi
Raspberry Pi I2S on port 3
AUX ADC Inputs
Generic I2C connectors
These go to the slave port These are 3v3 lines only!
I2S Inputs
See ADAU1452 datasheet for details Inputs are highly flexible Raspberry Pi audio on Channel 3
I2S Outputs
See ADAU1452 datasheet for details Outputs are highly flexible Raspberry Pi audio on Channel 3
These are 3v3 max input They have some protection but don't push it!
Copyright Paul Janicki 2015 Licensed under the TAPR Open Hardware License (www.tapr.org/OHL). This documentation is distributed WITHOUT ANY EXPRESS OR IMPLIED WARRANTY, INCLUDING OF MERCHANTABILITY, SATISFACTORY QUALITY AND FITNESS FOR A PARTICULAR PURPOSE.
Unused IO to generic connectors

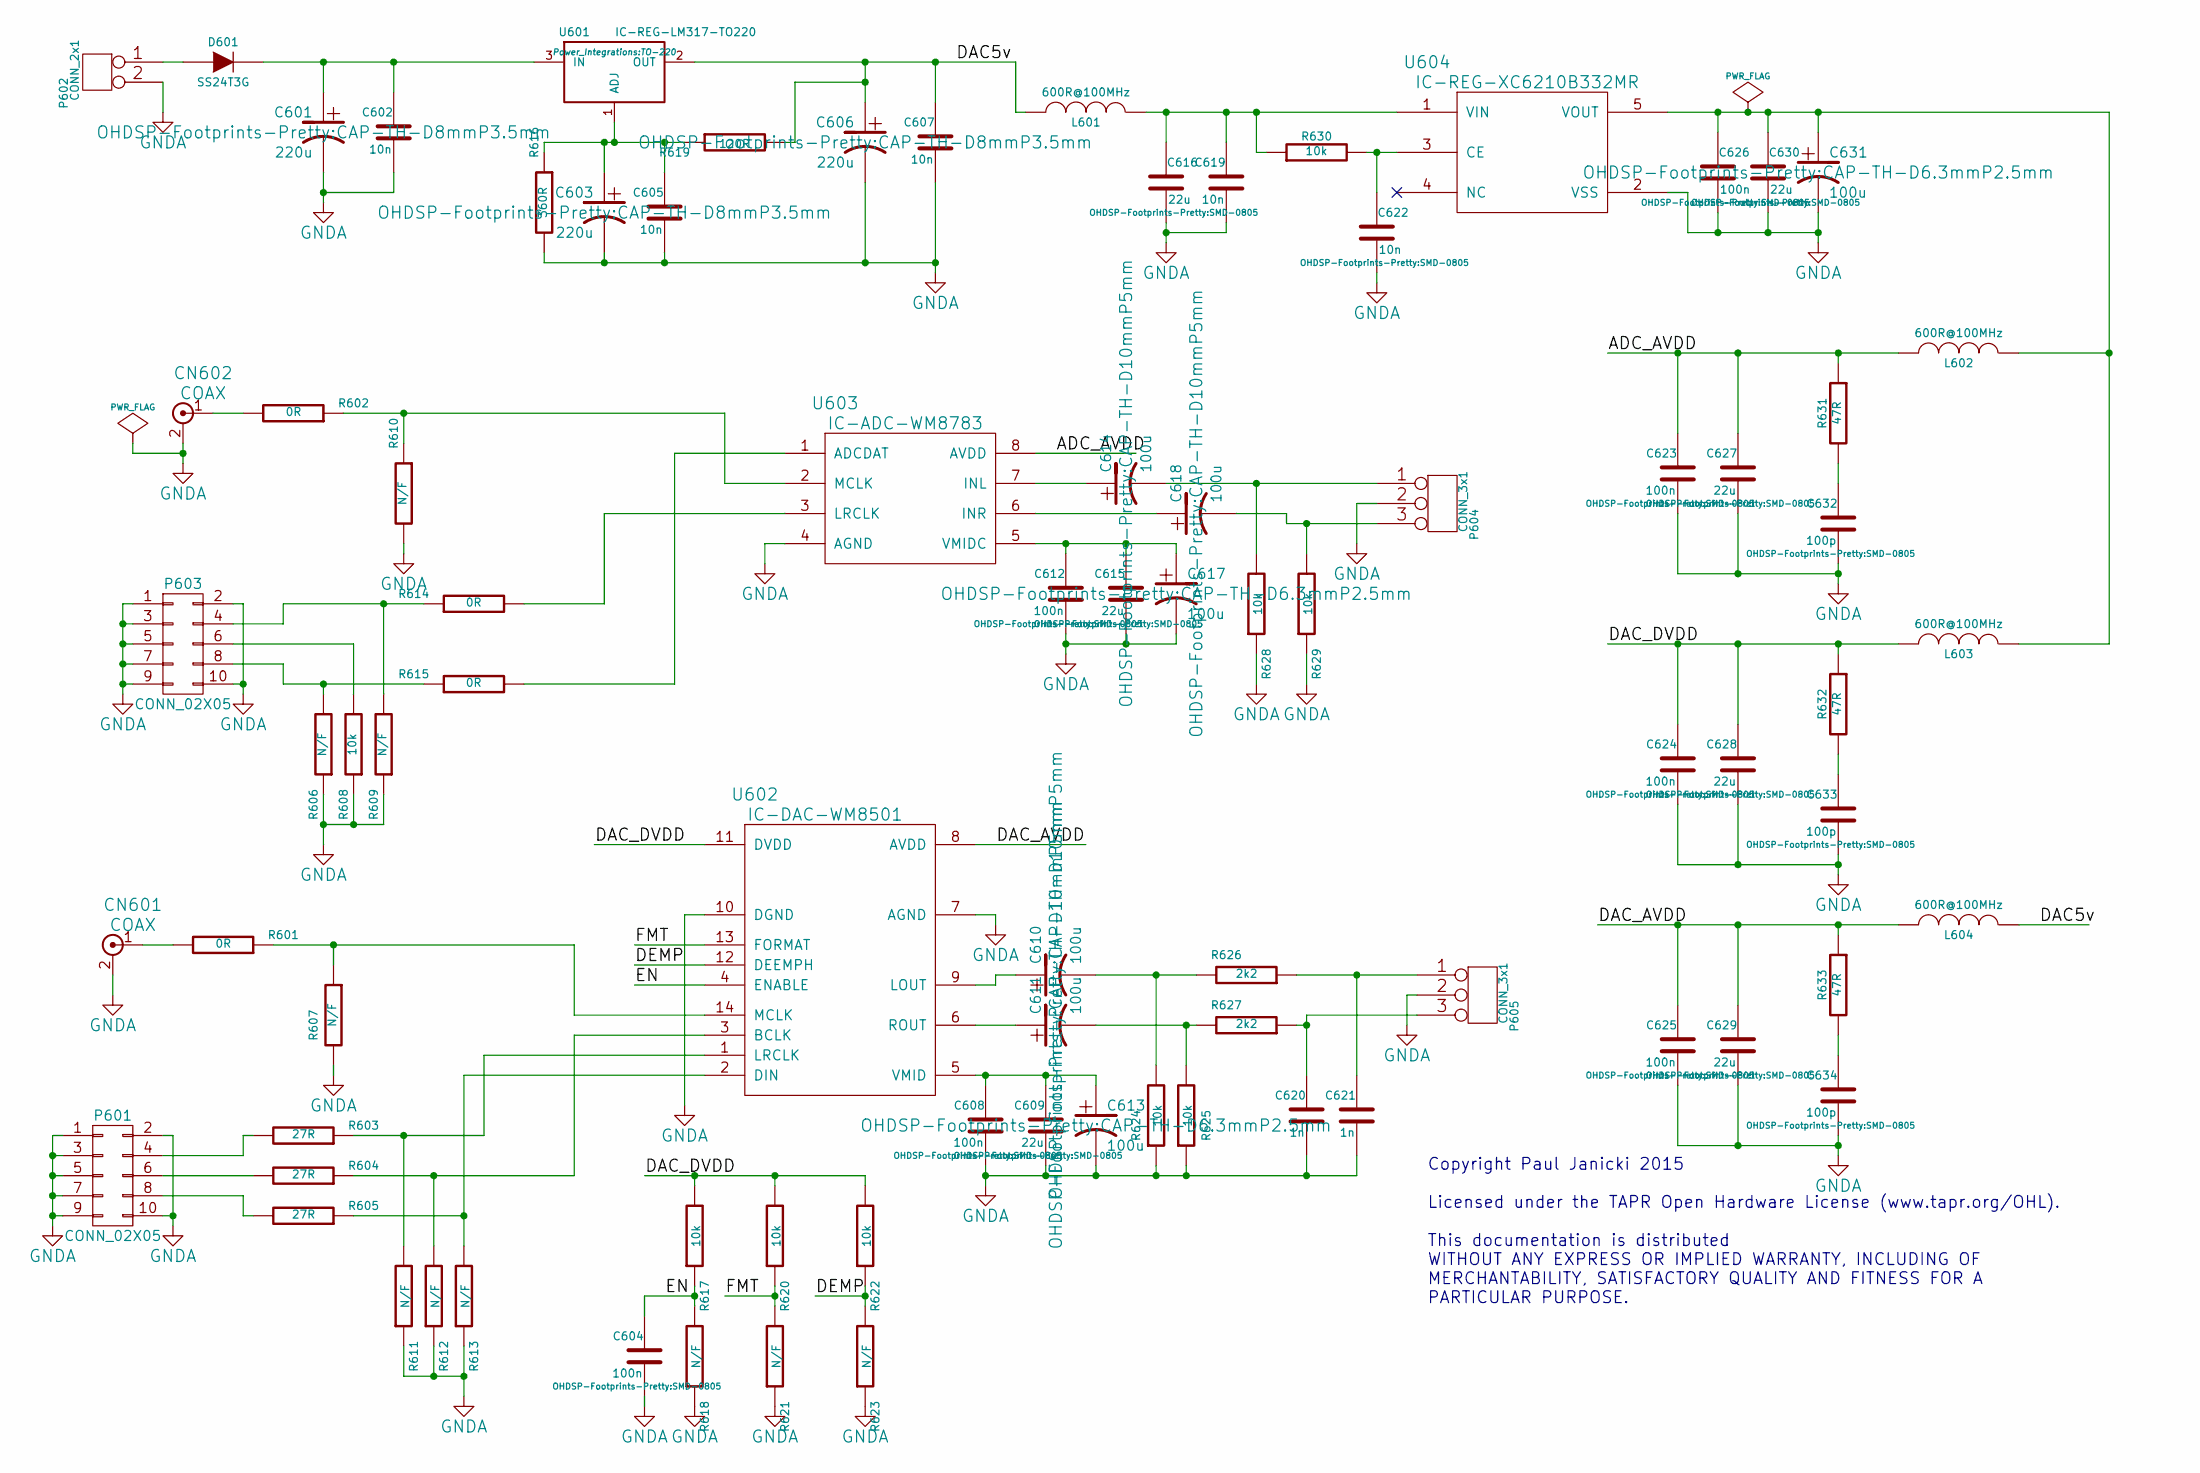
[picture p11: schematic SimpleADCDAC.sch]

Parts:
C601, C603, C606: 220u; CAP-TH-D8mmP3.5mm
C602, C605, C607, C619: 10n; CAP_TH_5mm
C604, C608, C612, C623, C624, C625, C626: 100n; SMD-0805
C609, C615, C616, C627, C628, C629, C630: 22u; SMD-0805
C610, C611, C614, C618: 100u; CAP-TH-D10mmP5mm
C613, C617, C631: 100u; CAP-TH-D6.3mmP2.5mm
C620, C621: 1n; SMD-0805
C622: 10n; SMD-0805
C632, C633, C634: 100p; SMD-0805
CN601, CN602: COAX; CONN-RF-UFL
D601: SS24T3G; DIODE-SMB
L601, L602, L603, L604: 600R@100MHz; SMD-0805
P601, P603: CONN_02X05; CONN_DIL_2X5
P602: CONN_2x1; CONN-SCREW-2WAY-5mm-5.08mm
P604, P605: CONN_3x1; CONN_SIL_3
R601, R602, R614, R615: 0R; SMD-0805
R603, R604, R605: 27R; SMD-0805
R606, R607, R609, R610, R611, R612, R613, R618, R621, R623: N/F; SMD-0805
R608, R617, R620, R622, R624, R625, R628, R629, R630: 10k; SMD-0805
R616: 360R; SMD-0805
R619: 120R; SMD-0805
R626, R627: 2k2; SMD-0805
R631, R632, R633: 47R; SMD-0805
U601: IC-REG-LM317-TO220; TO-220
U602: IC-DAC-WM8501; IC_SOIC_14
U603: IC-ADC-WM8783; IC_SOIC_8
U604: IC-REG-XC6210B332MR; IC-SOT25

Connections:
/SimpleADCDAC/ADC_AVDD: C623.1, C627.1, L602.2, R631.1, U603.8 (AVDD)
/SimpleADCDAC/DAC5v: C606.1, C607.1, L601.2, L604.1, R619.2, U601.2 (OUT)
/SimpleADCDAC/DAC_AVDD: C625.1, C629.1, L604.2, R633.1, U602.8 (AVDD)
/SimpleADCDAC/DAC_DVDD: C624.1, C628.1, L603.2, R617.2, R620.2, R622.2, R632.1, U602.11 (DVDD)
/SimpleADCDAC/DEMP: R622.1, R623.2, U602.12 (DEEMPH)
/SimpleADCDAC/EN: C604.1, R617.1, R618.2, U602.4 (ENABLE)
/SimpleADCDAC/FMT: R620.1, R621.2, U602.13 (FORMAT)
GNDA: C601.2, C602.2, C603.2, C604.2, C605.2, C606.2, C607.2, C608.2, C609.2, C612.2, C613.2, C615.2, C616.2, C617.2, C619.2, C620.2, C621.2, C622.2, C623.2, C624.2, C625.2, C626.2, C627.2, C628.2, C629.2, C630.2, C631.2, C632.2, C633.2, C634.2, CN601.2, CN602.2, P601.1, P601.2, P601.3, P601.5, P601.7, P601.9, P601.10, P602.2, P603.1, P603.2, P603.3, P603.5, P603.7, P603.9, P603.10, P604.2, P605.2, R606.1, R607.2, R608.1, R609.1, R610.2, R611.1, R612.1, R613.1, R616.2, R618.1, R621.1, R623.1, R624.1, R625.1, R628.1, R629.1, U602.7 (AGND), U602.10 (DGND), U603.4 (AGND), U604.2 (VSS)
unnamed: C601.1, C602.1, D601.2 (K), U601.3 (IN)
unnamed: C603.1, C605.1, R616.1, R619.1, U601.1 (ADJ)
unnamed: C608.1, C609.1, C613.1, U602.5 (VMID)
unnamed: C610.1, U602.9 (LOUT)
unnamed: C610.2, R624.2, R626.2
unnamed: C611.1, U602.6 (ROUT)
unnamed: C611.2, R625.2, R627.2
unnamed: C612.1, C615.1, C617.1, U603.5 (VMIDC)
unnamed: C614.1, U603.7 (INL)
unnamed: C614.2, P604.1, R628.2
unnamed: C616.1, C619.1, L601.1, R630.1, U604.1 (VIN)
unnamed: C618.1, U603.6 (INR)
unnamed: C618.2, P604.3, R629.2
unnamed: C620.1, P605.3, R627.1
unnamed: C621.1, P605.1, R626.1
unnamed: C622.1, R630.2, U604.3 (CE)
unnamed: C626.1, C630.1, C631.1, L602.1, L603.1, U604.5 (VOUT)
unnamed: C632.1, R631.2
unnamed: C633.1, R632.2
unnamed: C634.1, R633.2
unnamed: CN601.1, R601.2
unnamed: CN602.1, R602.2
unnamed: D601.1 (A), P602.1
unnamed: P601.4, R603.2
unnamed: P601.6, R604.2
unnamed: P601.8, R605.2
unnamed: P603.4, R609.2, R614.1
unnamed: P603.6, R608.2
unnamed: P603.8, R606.2, R615.1
unnamed: R601.1, R607.1, U602.14 (MCLK)
unnamed: R602.1, R610.1, U603.2 (MCLK)
unnamed: R603.1, R611.2, U602.1 (LRCLK)
unnamed: R604.1, R612.2, U602.3 (BCLK)
unnamed: R605.1, R613.2, U602.2 (DIN)
unnamed: R614.2, U603.3 (LRCLK)
unnamed: R615.2, U603.1 (ADCDAT)

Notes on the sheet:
Copyright Paul Janicki 2015 Licensed under the TAPR Open Hardware License (www.tapr.org/OHL). This documentation is distributed WITHOUT ANY EXPRESS OR IMPLIED WARRANTY, INCLUDING OF MERCHANTABILITY, SATISFACTORY QUALITY AND FITNESS FOR A PARTICULAR PURPOSE.

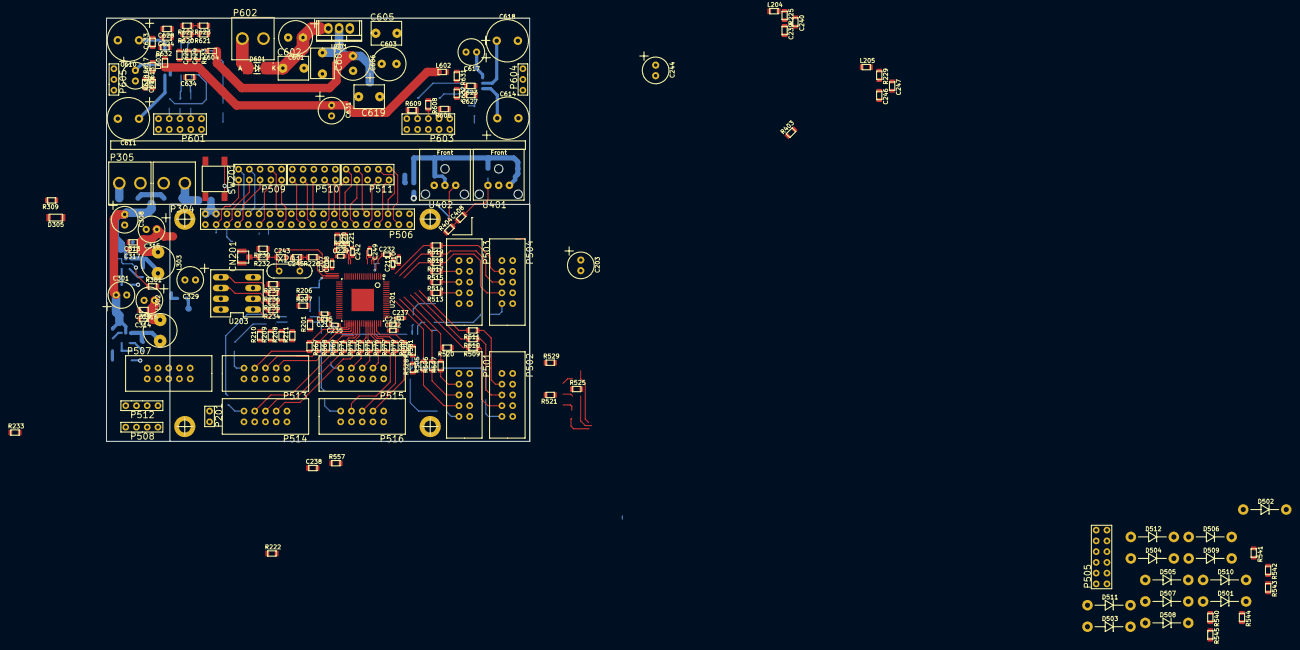
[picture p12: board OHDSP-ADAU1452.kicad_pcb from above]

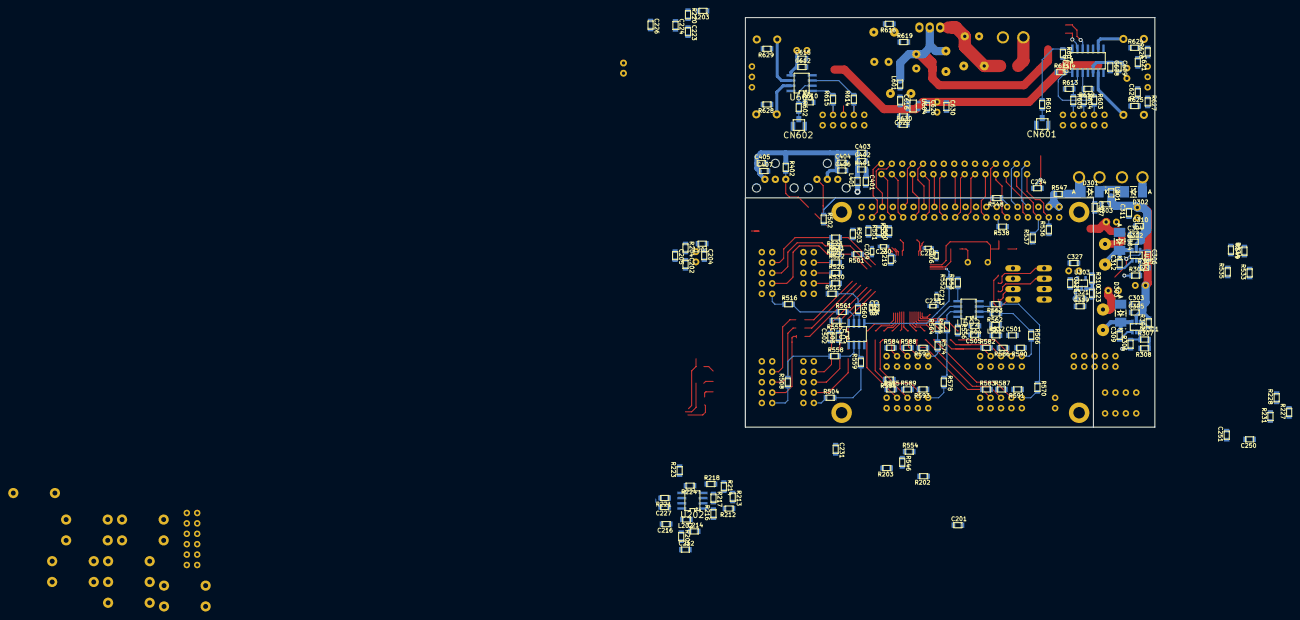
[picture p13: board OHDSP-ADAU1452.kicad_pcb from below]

Board: 4 copper layers, 100.0 x 100.0 mm, 376 parts (188 on the bottom side), 240 nets.

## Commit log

2015-02-24 Initial Commit
    Initial Commit to master containing KiCad Libraries
    [ohdsp-libs.kicad_pcb, ohdsp-libs.sch]
2015-02-24 Initial commit in ADAU1452
    Initial commit in ADAU1452, contains work in progress PCB layout and
    schematics. Schematics need reviewing.
    [ADAU1452 PSU.sch, ADAU1452.sch, ClockFanout.sch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]
2015-02-25 Schematic and PCB changes
    Changed and corrected some footprints, removed capacitors, updated
    documentation to change 1v5 SMPS to 1v2. Have not removed 1v2 LDO from
    schematic yet.
    [ADAU1452 PSU.sch, ADAU1452.sch, Connectors.sch]
2015-02-25 Remove 1v2 LDO
    Remove 1v2 LDO, not really needed...
    [ADAU1452 PSU.sch, ClockFanout.sch, Connectors.sch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]
2015-02-25 R305 value change for 1v2
    R305 value change for 1v2 from 1v5 value
    [ADAU1452 PSU.sch]
2015-02-26 Modifiy LFCSP72 to allow for attempted hand soldering...
    Modifiy LFCSP72 to allow for attempted hand soldering.
2015-02-26 Change ADAU1452 footprint, minor PCB changes
    [ADAU1452.sch, OHDSP-ADAU1452.kicad_pcb]
2015-02-26 Add 5mmx7mm crystal oscillator footprint for hand fit
    Add 5mmx7mm crystal oscillator footprint for hand fit
2015-02-26 Revert "Add 5mmx7mm crystal oscillator footprint for hand fit"
    This reverts commit a0ed6c03b1596703282a627aa3711e6da4f52fba.
2015-02-26 Revert "Revert "Add 5mmx7mm crystal oscillator footprint for hand fit""
    This reverts commit fe1a51017ccefdd16d0037da8ca0ddc103b71dd7.
2015-02-26 Rationalise the clock and clock fan-out schematics.
    Rationalise the clock and clock fan-out schematics.
    Removed one clock fan out buffer, still have 4 master audio clock
    outputs. Also removed local crytsal oscialltor, a low jitter crystal
    should perform as well, ADAU1452 has internal "dejittering" anyway.
    [ADAU1452 PSU.sch, ADAU1452.sch, ClockFanout.sch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]
2015-02-26 PCB work
    [OHDSP-ADAU1452.kicad_pcb]
2015-02-26 Added large pcb layout
    Added large pcb layout. Believe kicad expects 1 pcb per project so it
    has created an extra .pro file which should be ignored. This is a bit of
    a hack but it seems to work for now...
2015-02-26 Revert "Added large pcb layout"
    This reverts commit cdcde476aac2cbdae67bb5f0de8b4259defc0766.
2015-02-26 Add large pcb layout
    Added large pcb layout, kicad created additional .pro file which can be
    ignored, a bit of a hack but it works for the moment...
    [OHDSP-ADAU1452 - Large.kicad_pcb]
2015-02-26 Going 4 layer on smaller PCB
    Going 4 layer on smaller PCB
    [OHDSP-ADAU1452 - Large.kicad_pcb]
2015-02-26 Revert "Going 4 layer on smaller PCB"
    This reverts commit d1ec277a0becb058c7967dba94e28e7f31b1a00f.
    [OHDSP-ADAU1452 - Large.kicad_pcb]
2015-02-26 Revert "Revert "Going 4 layer on smaller PCB""
    This reverts commit a2928be1b12072271fc86fb10f3c648b88b658e1.
    [OHDSP-ADAU1452 - Large.kicad_pcb]
2015-02-26 Going 4 layer on small PCB
    Going 4 layer on small PCB
    [OHDSP-ADAU1452.kicad_pcb]
2015-02-27 PCB work
    More pcb work, some footprint changes, previous commit also had some
    minor footprint changes and 0R resistors added...
    [$ADAU1452.sch, ADAU1452.sch, OHDSP-ADAU1452.kicad_pcb]
2015-02-28 PCB work, footprint changes
    [OHDSP-ADAU1452.kicad_pcb]
2015-02-28 Footprint changes
    Footprint changes
    [ADAU1452.sch]
2015-03-02 PCB changes, minor schematic changes
    Removed switch on selfboot pin, as it has a jumper anyway... Removed
    SPI/I2C jumper for selfboot as sticking with serial EEPROM. Changed some
    component footprints (R207 to R216 0603 to 0805).
    [ADAU1452.sch, OHDSP-ADAU1452.kicad_pcb]
2015-03-03 PCB work, removed a cap
    [ClockFanout.sch, OHDSP-ADAU1452.kicad_pcb]
2015-03-03 Added SMD tact switch foorprint
    Added SMD tact switch foorprint
2015-03-03 PCB Work, change reset switch to SMD
    [ADAU1452.sch, OHDSP-ADAU1452.kicad_pcb]
2015-03-04 PCB Work, minor schematic changes
    Removed cap and LED, changed one net label
    [ADAU1452 PSU.sch, ADAU1452.sch, ClockFanout.sch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]
2015-03-04 PCB work, remove 5v from I2C headers
    [Connectors.sch, OHDSP-ADAU1452.kicad_pcb]
2015-03-04 PCB work, added manual reset to Pi header
    [ADAU1452.sch, Connectors.sch, OHDSP-ADAU1452.kicad_pcb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]
2015-03-04 PCB work
    Also playing with via sizes...
    [OHDSP-ADAU1452.kicad_pcb]
2015-03-07 PCB work, removed pointless connector
    [Connectors.sch, OHDSP-ADAU1452.kicad_pcb]
2015-03-10 PCB work, extra Pi GPIO to external connectors
    PCB work, extra Pi GPIO to external connectors
    [Connectors.sch, OHDSP-ADAU1452.kicad_pcb]
2015-03-10 PCB work, Running Electrical Rule Check
    PCB work, Running Electrical Rule Check:
    Added no connects to schematics, added missing pull up on EEPROM, remove
    USB_CLK/USB_RESET label on USB/I2C header and added NC. Minor change on
    Pi connectors.
    Removed old large PCB file.
    [ADAU1452 PSU.sch, ADAU1452.sch, ClockFanout.sch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]
2015-03-10 PCB work, ADAU reset changes
    Added caps to reset lines
    [ADAU1452 PSU.sch, ADAU1452.sch, ClockFanout.sch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]
2015-03-11 PCB work, SPDIF filter caps changed
    [Connectors.sch, OHDSP-ADAU1452.kicad_pcb, SPDIF.sch]
2015-03-11 PCB work
    Corrected trace width notes, need to change PCB traces to match
    [OHDSP-ADAU1452.kicad_pcb]
2015-03-12 Add new ADC and DAC
    Add WM8501 DAC and WM8783 ADC and SOIC 14 footprint
2015-03-12 Adding Simple ADC and DAC option
    Adding Simple ADC and DAC option
    Will see if it fits in the remaining space for a 10cmx10cm PCB, have to
    pay for the space for anysize up to 10x10cm to may as well use it.
    [ADAU1452 PSU.sch, ADAU1452.sch, ClockFanout.sch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]
2015-03-12 Adding ADC/DAC
    [OHDSP-ADAU1452.kicad_pcb, SimpleADCDAC.sch]
2015-03-12 Add 5mm PP/MKP cap footprint
2015-03-12 Adding DAC/ADC
    [OHDSP-ADAU1452.kicad_pcb, SimpleADCDAC.sch]
2015-03-12 PCB work, added DAC/ADC
    [OHDSP-ADAU1452.kicad_pcb, SimpleADCDAC.sch]
2015-03-13 PCB work
    Need to finish sorting SPI lines, currently a mix of 0.25mm and 0.2mm on
    the same traces...
    [OHDSP-ADAU1452.kicad_pcb]
2015-03-26 Add I2C EEPROM
2015-03-26 Add 2x10 connector
2015-03-26 Correct NCP700B pin out
2015-03-30 Add LT1374, inductor and SMC diode
2015-03-30 WIP
    Removed Slave SPI as only really need I2C
    Should free up some space on the board.
    May look to change U.fl to SMA
    [ADAU1452.sch, Connectors.sch, OHDSP-ADAU1452.kicad_pcb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]
2015-03-31 Add 4 pin DIL crystal oscillator
2015-04-01 Add 2x5 DIL box header footprint
2015-04-08 Add 2x10 2.54mm box header footprint
2015-04-11 Playing with different connectors....
    [OHDSP-ADAU1452.kicad_pcb]
2015-05-24 WIP
    Add master audio clock to I2S headers.
    [ADAU1452 PSU.sch, ADAU1452.sch, Connectors.sch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]
2015-05-29 WIP
    Remove unneeded parts around SPI EEPROM
    [ADAU1452 PSU.sch, ADAU1452.sch, Connectors.sch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]
2015-05-29 WIP
    Simplify PSU
    [ADAU1452 PSU.sch, Connectors.sch, OHDSP-ADAU1452.kicad_pcb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]
2015-06-04 Add AD1937 CODEC- No footprint
    Added AD1937 CODEC, need to add LQFP64 10x10 footprint
2015-06-05 Add LQFP64 Footprint
